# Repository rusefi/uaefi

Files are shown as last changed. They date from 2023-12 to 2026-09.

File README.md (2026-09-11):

# Ultra Affordable EFI

🟢[$275 base model rusEFI store](https://www.shop.rusefi.com/shop/p/uaefi-ultra-affordable-efi)🟢

## Community Support

🔴Community support ONLY 🔴 https://www.facebook.com/groups/rusEfi 🔴 [Discord](https://github.com/rusefi/rusefi/wiki/Discord)🔴 [Commercial Support](https://www.shop.rusefi.com/shop/p/details-about-rusefi-ecu-technical-support) 🔴

## Technical Details

Open Source KiCAD hardware powered by [Hellen-One](https://github.com/andreika-git/hellen-one)

Powered by [rusEFI firmware](https://github.com/rusefi/rusefi)

[User Documentation](https://github.com/rusefi/rusefi/wiki/uaEFI)





## MCU options

1mb of flash is _required_.

One day we shall try https://jlcpcb.com/partdetail/Stmicroelectronics-STM32F427VIT6%2FC57097#EC or https://jlcpcb.com/partdetail/Stmicroelectronics-STM32F437VIT7%2FC1338578#EC

## HOWTO JLCPCB

You would need three files from ``boards/uaefi-a/board`` folder to place your JLCPB Assembly order: gerber.zip BOM-JLC.csv and CPL.csv

### Q: having trouble with opening uaefi board project. library path seems ok, i do not know how to solve missing modules issue

A: missing modules are closed source. they are filled in by github magic
github magic combines gerbers and spits out a complete bom/pcl/new gerbers to upload to jlc/friends. See https://github.com/rusefi/hellen-one/tree/master?tab=readme-ov-file#tldr for more info

### Q: Magic modules? How do I see schematics of those?

A: https://github.com/rusefi/hellen-one has full documentation for each module

### Q: Something wrong with BOM?

A: Nope, that's normal nothing to worry about click 'Continue'.



### Q: how do I get more RAM for Lua?

A: fabricate with STM32F42xVI firmware would defect extra RAM and give you extra Lua. Once your script does not fit into STM32F42xVI it's F7 time or help us leverage F413.

### Q: I've place an order with JLCPCB and I see scary looking wrong orientation?

A: that's expected. See [boards/uaefi-c/board](boards/uaefi-c/board) ``Original*.png`` files and ``Produce*.png`` after JLCPCB manual review process.

## Bluetooth power issue fix

It was found that board with installed BT module may be affected by power issue.

During power on BT module consume too much inrush current on 3.3V line causing 3.3V drop below MCU reset hreshold. This may lead to unstable start or infinity reset loop.

To fix this please install additional capacitors to 5V and 3.3V powerlines.

Polarized electrolytic capacitors with at least 10V rating and extended temperature range are recommended. Tantalum and solid electrolytic capacitors are also suitable.

**Please carefully follow illustrated polarity.**

33..47uF should be added to 5V powerrail. [This](https://www.digikey.com/en/products/detail/w%C3%BCrth-elektronik/860020372004/5727028) or [this](https://www.digikey.com/en/products/detail/w%C3%BCrth-elektronik/860080372001/5727224) or [any of these](https://www.digikey.com/en/products/filter/aluminum-electrolytic-capacitors/58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).



And 220..470uF should be added to 3.3V powerrail. [This](https://www.digikey.com/en/products/detail/w%C3%BCrth-elektronik/860010273011/5726952) or [this](https://www.digikey.com/en/products/detail/w%C3%BCrth-elektronik/860020273011/5727148) or [any of these](https://www.digikey.com/en/products/filter/aluminum-electrolytic-capacitors/58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).



## HOWTO EGT chip

This board has a placeholder for MAX31855 (or MAX6675) termocouple-to-digital chip. **This chip is not populated by default!**

Screenshot from 2025-09-26 11-15-15

D8 is **optional** ESD protection and also is not populated by default. You need to solder U4 only, D8 is optional. All passive components are already populated.

**MAX31855** works without addtional modification.

For **MAX6675** connect EGT- to GNDA either on J2 "C" connector or just short C28 (replace with 0R).

Screenshot from 2025-09-26 11-19-41

## [EXPERIMENTAL] How to make MAX9924 work with low tooth count trigger wheel

In some cases user may need two VR inputs on UAEFI and both trigger wheels are low-tooth count.

In default configuration MAX9924 does not work with low count trigger wheels because of its "adaptive peak threshold" and its watchdog.

Screenshot from 2025-10-12 16-58-30

On UAEFI MAX9924 is configured in **A2 mode**.

Screenshot from 2025-10-12 16-59-49

**B mode** allow use of MAX9924 with low count trigger wheels. But external Bias and Thresholt voltages should be allpied. Both can be sources from UAEFI Discrete VR module.

List of modifications:
1. pin 6: ZERO_EN connect to VCC instead of GND.
2. pin 4: supply 2.5 V instead of GND
3. pin 8: EXT, supply external threshold voltage

Pins 4 and 6 needs to be lifted from PCB to be disconnected from GND. Pin 8 initially is not connected to any circuit.

Use hot air gun to de-solder whole chip. Then twist pins 4 and 6 up so both do not touch PCB. Then solder chip back to PCB

Now use thin wire to connect:
1. pin 6 to pin 10 of the same chip.
2. pin 4 to **Vref** at R769 + C754. See [iBOM](https://github.com/rusefi/uaefi/blob/main/boards/uaefi-d/board/uaefi-d-ibom.html) for its locations
3. pin 8 to **thresh_high** at U756 pin 1. See [iBOM](https://github.com/rusefi/uaefi/blob/main/boards/uaefi-d/board/uaefi-d-ibom.html) for its locations



Now MAX9924 VR input uses same threshold vs RPM settings that is set for Descrete VR input. And it is cabable to work with low tooth count trigger wheels without noise issues.

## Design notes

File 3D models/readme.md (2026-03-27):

Unofficial enclosure By Kim https://www.thingiverse.com/thing:6498664

Unofficial enclosure By Light-r4y https://github.com/Light-r4y/uaEFI_case

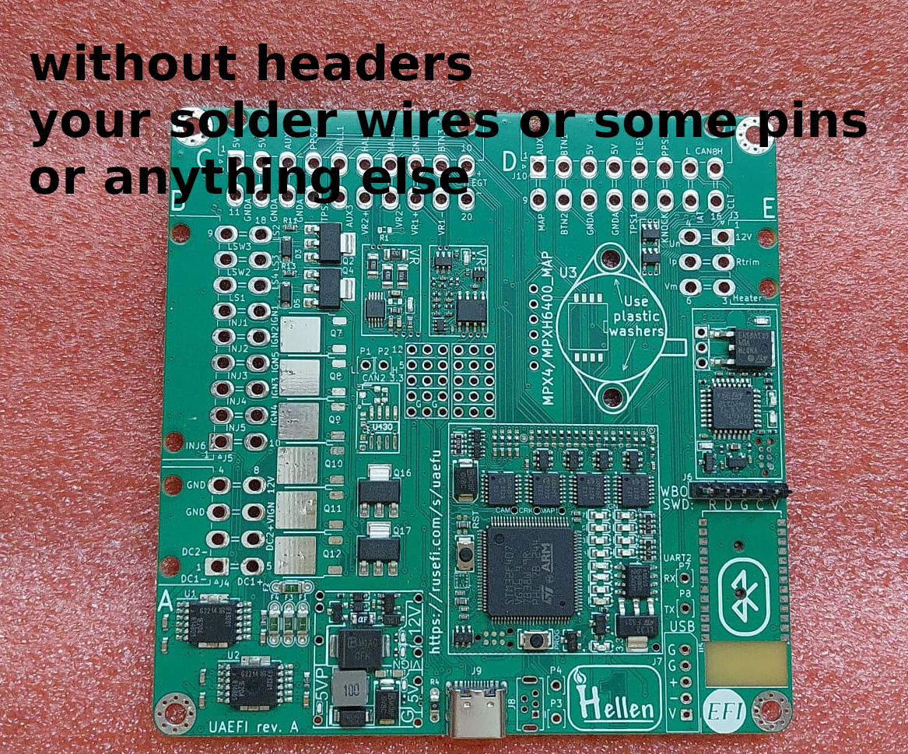
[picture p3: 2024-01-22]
docs/without-headers.png

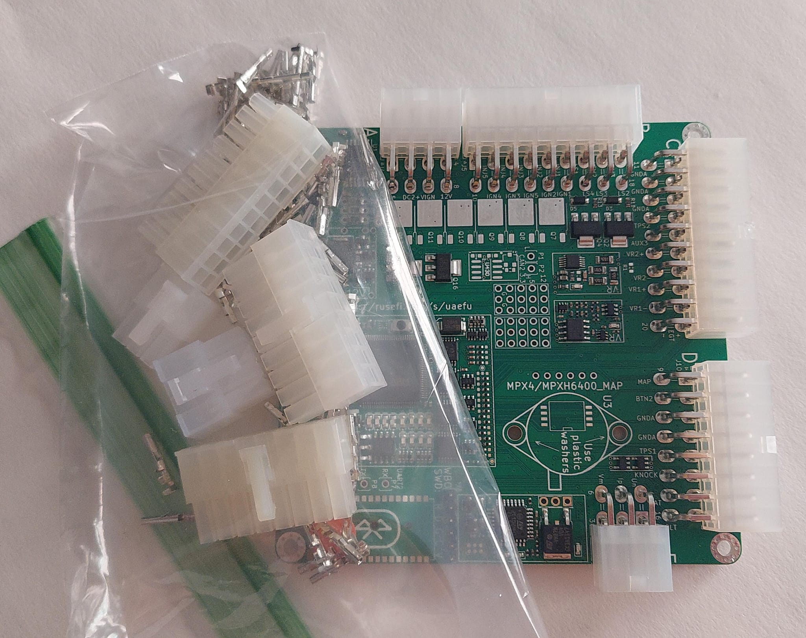
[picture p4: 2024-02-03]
docs/with-crimp-kit.jpg

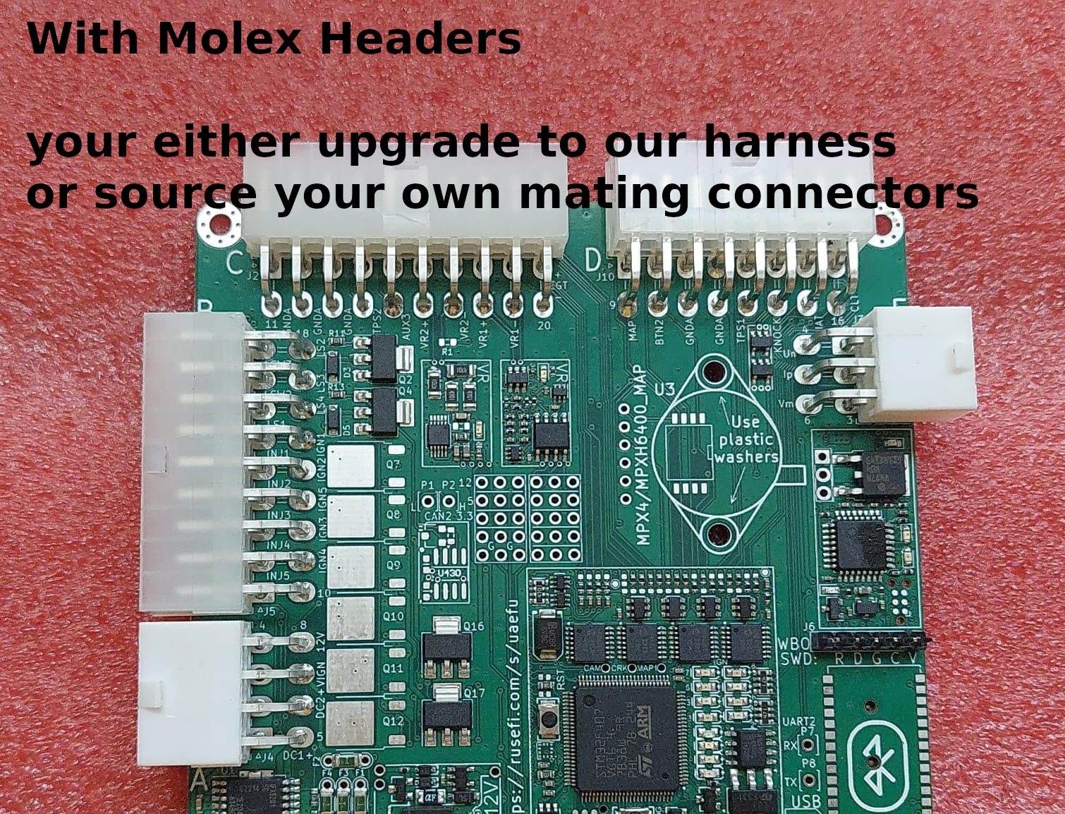
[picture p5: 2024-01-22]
docs/with-headers.png

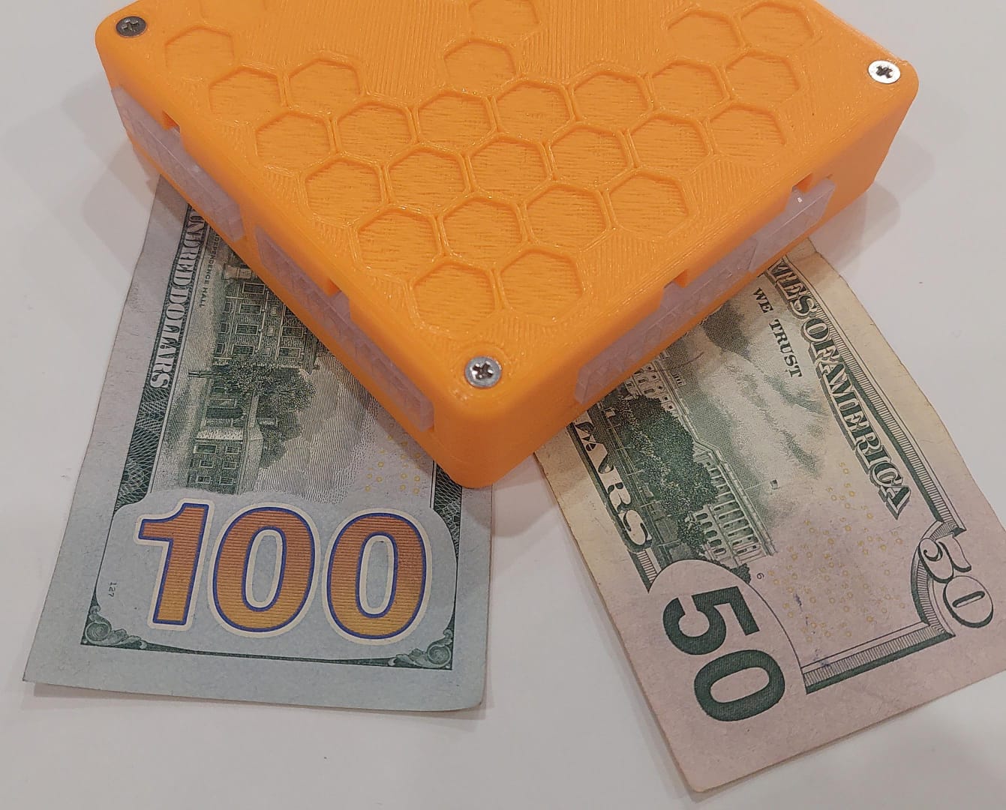
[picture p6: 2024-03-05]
docs/orange-150.jpg

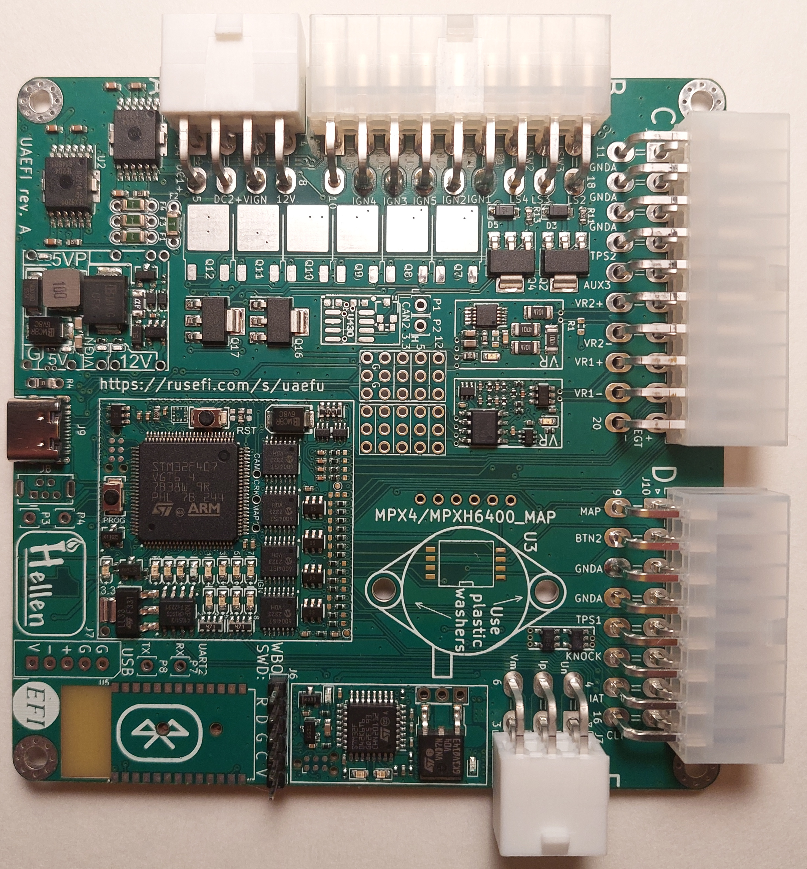
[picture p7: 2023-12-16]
docs/uaefi-a-top-high-res.jpg

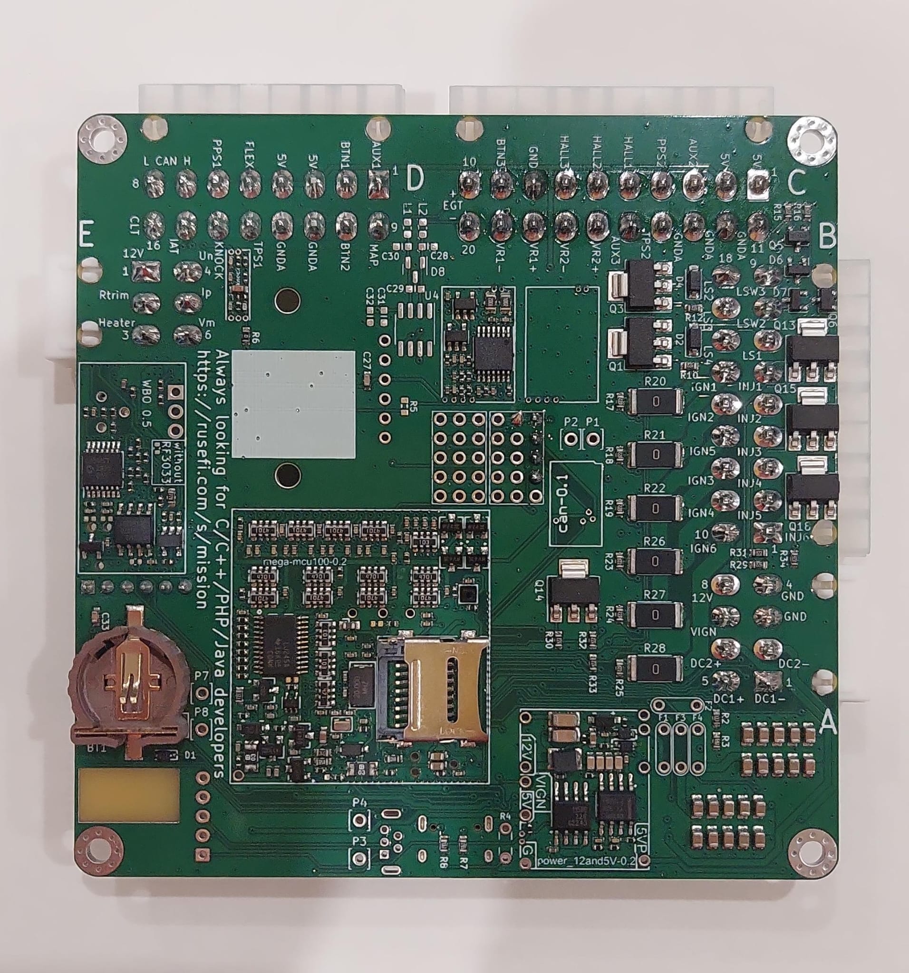
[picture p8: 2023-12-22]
docs/base-bottom.jpg

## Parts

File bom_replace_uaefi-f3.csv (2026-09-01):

#include hellen-one/global-replace.csv
# remove +5V pull-ups from SPI1, because we use it with +3.3v accelerometer
R103,
R105,
# remove jumper resistor connecting BOOT1 with A22 input line, because we use STM32F4
R131,
#CAN wakeup disabled, O2S input enabled
R145,
#PWR_EN not used as GPIO
R142,
# cost reduction
U106,
# DNP BLUETOOTH JDY
U5,
# DNP EGT
D8,
U4,
# STM32F407VGT6 is very cheap
U105,"STM32F407VGT6","LQFP100","C12345"
#without CAN2
"C430,C431,D430,R430,U430",
#VNLD5090
"U6,U7,U8,U9,U10,U11","VNLD5090","SO-8","C222209"
#79 RTC battery drain
D107,
# availability and cost reduction
J2,"5569-20A2","2x10P 2 4.2mm Female pin 4.2mm","C2845795"
J3,"5569-06A2","2x3P 2 4.2mm 4.2mm 3 Brass Push-Pull","C19188572"
J4,"5569-08A2","2x4P 2 Tin 4.2mm Female 4.2mm","C388760"
J5,"5569-18A2","2x9P 2 4.2mm Female 4.2mm 9 Right-Angle","C725776"
J10,"39301160","02x08_4.2mm","C5355564"
# Q1 options
# ZXMS6005SGTA C174042
# ZXMS6005DGTA C174045
# NCV8440ASTT3G C604063
# would VNL5160 work? would VNL5160 be the cheapest option?
# cost
"D411","PSM712-LF","SOT-23","C5180294"
# same board ID as rev A for now!
#include hellen-one/board_id/generated/board_id_uaefi-a.csv
#include bom_pullups_uaefi-f3.csv

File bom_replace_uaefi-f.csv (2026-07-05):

#include hellen-one/global-replace.csv
# remove +5V pull-ups from SPI1, because we use it with +3.3v accelerometer
R103,
R105,
# remove jumper resistor connecting BOOT1 with A22 input line, because we use STM32F4
R131,
#CAN wakeup disabled, O2S input enabled
R145,
#PWR_EN not used as GPIO
R142,
# DC-DC Inductor
L421,"MWSA0503S-100MT","MWSA0503","C408412"
L420,"NLCV32T-2R2M-EF","L1210","C250227"
# fuses
F410,"nSMD050-24V","SMD1206","C70076"
# replacement not needed "F1,F2,F3,F4","5A","F1206","C553924"
# TLS115
U411,"TLS115B0EJXUMA1","PG-DSO-8","C3747428"
#MAX9142
U754,"TLV3202AIDR","SO8","C129325"
# cost reduction
U106,
# DNP BLUETOOTH JDY
U5,
# more proper part and shelf
"U1,U2","TLE9201SG","Infineon_PG-DSO-12-11","C2653438"
# DNP EGT
D8,
U4,
R420,"1","R0402","C2770750"
U107,"LPS22","HLGA-10L","C2827824"
U410,"LP2981-33DBVR","SOT-23-5","C129997"
U602,"STM32F042K6T7","LQFP-32","C1337340"
"C603","33n","C0402","C106862"
#Knock capacitor
"C471","3.3n","C0402","C107028"
# max9924
U771,"MAX9924UAUB+T","MSOP10","C5145181"
# STM32F407VGT6 is very cheap
U105,"STM32F407VGT6","LQFP100","C12345"
#without CAN2
"C430,C431,D430,R430,U430",
#20MHz crystal
# replacement not needed Y102,"TXM20M0002503LFBEO00T","SMD5032-2P","C362485"
#SD Card
J100,"TF-014-H16","SMD","C125814"
#board ID capacitor shortage
"C123,C133","1u","C0603","C14664"
R609,"61.9","R0603","C321964"
#VNLD5090
"U6,U7,U8,U9,U10,U11","VNLD5090","SO-8","C222209"
#mux
"U755,U756","WAS3157B-6","SOT-363","C213161"
#78 IGN buf switch to SN74LXCH8T245PWR
U103,"SN74LXCH8T245PWR","TSSOP-24","C2918963"
#79 RTC battery drain
D107,
# availability and cost reduction
J2,"5569-20A2","2x10P 2 4.2mm Female pin 4.2mm","C2845795"
J3,"5569-06A2","2x3P 2 4.2mm 4.2mm 3 Brass Push-Pull","C19188572"
J4,"5569-08A2","2x4P 2 Tin 4.2mm Female 4.2mm","C388760"
J5,"5569-18A2","2x9P 2 4.2mm Female 4.2mm 9 Right-Angle","C725776"
J10,"39301160","02x08_4.2mm","C5355564"
# Q1 options
# ZXMS6005SGTA C174042
# ZXMS6005DGTA C174045
# NCV8440ASTT3G C604063
# would VNL5160 work? would VNL5160 be the cheapest option?
# cost
"D411","PSM712-LF","SOT-23","C5180294"
#LEDs
"D106","YELLOW_LED","LED0603","C165983"
"D751,D771,D601,D104,D108","GREEN_LED","LED0603","C965804"
"D602,D105,D109,D110,D111,D112,D113,D114,D115,D116","BLUE_LED","LED0603","C497940"
"LED1, LED2, LED3, LED4","BLUE_LED","LED0402","C434447"
# same board ID as rev A for now!
#include hellen-one/board_id/generated/board_id_uaefi-a.csv
#include bom_pullups_uaefi-f.csv

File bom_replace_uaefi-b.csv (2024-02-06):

# remove +5V pull-ups from SPI1, because we use it with +3.3v accelerometer
R103,
R105,
# remove jumper resistor connecting BOOT1 with A22 input line, because we use STM32F4
R131,
#CAN wakeup disabled, O2S input enabled
R145,
#PWR_EN not used as GPIO
R142,
# DC-DC Inductor
L421,"MWSA0503S-100MT","MWSA0503","C408412"
L420,"NLCV32T-2R2M-EF","L1210","C250227"
# fuses
F410,"nSMD050-24V","SMD1206","C70076"
# TLS115
U411,"TLS115B0EJXUMA1","PG-DSO-8","C3743696"
# cost reduction
U106,
# STM32F407VGT6 is very cheap
U105,"STM32F407VGT6","LQFP100","C12345"
#without CAN2
"C430,C431,D430,R430,U430",
#20MHz crystal
Y102,"TXM20M0002503LFBEO00T","SMD5032-2P","C362485"
#SD Card
J100,"TF-014-H16","SMD","C125814"
#board ID capacitor shortage
C133,"1u","C0603","C519559"
#mux
"U755,U756","WAS3157B-6","SOT-363","C213161"
# availability and cost reduction
J2,"5569-20A2","2x10P 2 4.2mm Female pin 4.2mm","C2845795"
J3,"5569-06A2","2x3P 2 4.2mm 4.2mm 3 Brass Push-Pull","C190915"
J4,"5569-08A2","2x4P 2 Tin 4.2mm Female 4.2mm","C388760"
J5,"5569-18A2","2x9P 2 4.2mm Female 4.2mm 9 Right-Angle","C725776"
J10,"39301160","02x08_4.2mm","C5355564"
# Q1 options
# ZXMS6005SGTA C174042
# ZXMS6005DGTA C174045
# NCV8440ASTT3G C604063
# would VNL5160 work? would VNL5160 be the cheapest option?
# cost
"D6, D7, D411","PSM712-LF","SOT-23","C5180294"
#LEDs
"D751,D771,D601,D104,D108","GREEN_LED","LED0603","C965804"
"D602,D105,D109,D110,D111,D112,D113,D114,D115,D116","BLUE_LED","LED0603","C497940"
"LED1, LED2, LED3, LED4","BLUE_LED","LED0402","C2844007"
# same board ID as rev A for now!
#include hellen-one/board_id/generated/board_id_uaefi-a.csv
#include bom_pullups_uaefi-b.csv

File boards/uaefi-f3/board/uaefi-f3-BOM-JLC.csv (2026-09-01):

Comment | Designator | Footprint | LCSC Part #
CR1220 | BT1 | CR1220-2 | C70381
10u | C1, C2, C3, C4, C5, C6, C7, C8, C9, C10, C14, C15, C16, C17, C18, C19, C20, C21, C22, C23 | C0805 | C15850
100n | C11, C24, C27, C29, C31, C33, C772 | C0603 | C14663
10n | C12, C13, C25, C26, C28, C30 | C0603 | C57112
1u | C32 | C0603 | C15849
1N4148WS | D1, D410, D412, D413, D414 | SOD-323 | C2128
B5819W | D2, D3, D4, D5, D416, D417, D101 | SOD-123 | C8598
Fuse | F1, F2, F3, F4 | Fuse_1206_3216Metric_Pad1.42x1.75mm_HandSolder | C182446
50mA | F5, F6, F7, F8, F9, F10 | Fuse_0603_1608Metric | C369141
Conn_01x06 | J6 | PinHeader_1x06_P2.54mm_Vertical | C37208
USB_C | J9 | USB_C | C2927038
470R@100MHz | L1, L2 | L_0603_1608Metric | C97853
33k | R2, R120 | R0603 | C4216
6.8k | R3 | R0603 | C23212
4.7k | R4, R9, R10, R11, R12, R13, R14, R15, R16, R29, R30, R31, R32, R33, R34, R41, R42, R43, R44, R45, R46, R47, R48, R49, R50, R51 | R0603 | C23162
0 | R6 | R0603 | C21189
5.6k | R7, R8 | R0603 | C23189
22 | R17, R18, R19, R23, R24, R25 | R0603 | C23345
0 | R20, R21, R22, R26, R27, R28 | R2512 | C25469
10k | R35, R36, R37, R752, R753 | R0805 | C17414
TLE9201SG | U1, U2 | Infineon_PG-DSO-12-11 | C2653438
47u | C410, C412 | C1206 | C96123
100n | C411, C413, C420, C470, C228 | C0402 | C307331
1u | C414, C415, C755, C758, C761, C762, C763, C765, C766, C767, C600, C607, C609, C610, C611 | C0402 | C52923
10u | C421, C422, C423, C424, C425 | C0603 | C96446
47u | C426 | C0603 | C140782
4.7u | C427, C616 | C0603 | C19666
10n | C428, C756, C757, C760, C764, C768, C769, C203, C202, C201, C200, C214, C215, C225, C226, C227 | C0402 | C15195
220p | C429 | C0402 | C1530
BAS416 | D415 | SOD-323 | C968040
SMCJ30A | D418 | SMC | C310046
SS34 | D420 | SMA | C8678
P6SMB6.8CA | D421, D205 | SMB | C78395
SMD1206P050TF/24 | F410 | SMD1206 | C369160
2.2uH | L420 | L1210 | C250227
MWSA0503-10uH | L421 | MWSA0503 | C325966
MHT136UGCT | LED1, LED2, LED3, LED4 | LED0402 | C434447
6.8k | R410, R413 | R0402 | C93940
33k | R411, R424, R425, R474 | R0402 | C25779
1 | R420 | R0402 | C25147
10k | R421, R426, R427, R757, R762, R763, R767, R768, R604, R605, R613, R614, R618, R619, R625, R102, R107, R108, R109, R121, R127, R128, R141, R219 | R0402 | C60490
68k | R422, R760, R602, R603 | R0402 | C137947
12k | R423, R472, R754 | R0402 | C25752
4.7k | R428, R144, R202, R201, R124, R126, R132 | R0402 | C25900
MIC5205-3.3YM5 | U410 | SOT23-5 | C129997
TLS115 | U411 | PG-DSO-8 EP | C3743696
LMR14020 | U420 | SOP8 | C187824
3.3n | C471 | C0402 | C26404
330p | C472 | C0402 | C13533
47p | C473 | C0402 | C1567
680p | C474 | C0603 | C1630
470k | R470 | R0402 | C137976
100k | R471, R473, R755, R756, R758, R759, R615, R621 | R0402 | C25741
LMV321IDBVR | U470, U471 | SOT23-5 | C7972
1n | C751, C135, C139, C141, C142, C211, C209, C208, C212, C213, C210, C143, C144, C145, C146 | C0402 | C1523
470n | C752 | C0402 | C47339
100n | C753, C754, C759, C601, C602, C605, C608, C612, C613, C614, C615, C617, C618, C100, C101, C105, C108, C111, C112, C113, C119, C120, C122, C124, C126, C127, C130, C134, C147, C180, C185, C190, C195, C220, C221, C222 | C0402 | C1525
LED-GREEN-0603 | D751, D771, D601, D104, D108 | LED-0603 | C965804
2.2k | R751, R122, R123, R146, R147 | R0402 | C25879
10 | R761, R764, R769, R606, R110, R111, R112, R113, R114, R115, R116, R117 | R0402 | C25077
1k | R765, R766, R600, R601, R616, R617, R622, R626, R627, R628 | R0402 | C11702
SRV05-4-P-T7 | U751, D102, D200, D202, D203, D206 | SOT23-6 | C85364
74AHC1G02 | U752, U757 | SOT23-5 | C7463
MCP6004 | U753, U600, U180, U185, U190, U195 | TSSOP14 | C50282
MAX9142 | U754 | SO8 | C129325
NC7SB3157P6X | U755, U756 | SOT-363 | C87403
1n | C771 | C0603 | C1588
22u | C773 | C0603 | C59461
4.7k | R771, R772, R773, R774 | R1206 | C17936
10k | R776, R777, R134 | R0603 | C167144
MAX9924UAUB+ | U771 | MSOP-10_3x3mm_P0.5mm | C143633
33n | C603 | C0402 | C106862
LED-RED-0603 | D600, D603, D103 | LED-0603 | C2286
LED-BLUE-0603 | D602, D105, D109, D110, D111, D112, D113, D114, D115, D116 | LED-0603 | C497940
PESD1CAN | D604, D100 | SOT-23 | C5261084
VNN7NV04PTR-E | Q600 | SOT-223 | C501115
22k | R607 | R0402 | C25768
47 | R608 | R0402 | C25118
61.9 | R609 | R0603 | C227998
20k | R610, R611, R612 | R0402 | C25765
27k | R620, R623 | R0402 | C25771
3.3k | R624 | R0402 | C25890
AD8628 | U601 | TSOT23-5 | C29309
STM32F042K6Tx | U602 | LQFP32 | C1337340
REF3033 | U603, U102 | SOT-23 | C36658
XC6206P332MR | U604 | SOT-23 | C5446
TJA1051T/3/1J | U605, U100 | SO8 | C38695
SN74LVC4245APWR | U103 | TSSOP24 | C2918963
SN74LVC1G06DCKR | U110 | SC-70-5 | C7828
SMD1206B035TF/16 | F100, F101 | R1206 | C269114
Molex MicroSD 47219-2001 | J100 | SDAMB-012 | C164170
LPS22HBTR | U107 | HLGA-10L | C2827824
LED-YELLOW-0603 | D106 | LED-0603 | C2287
LDL1117S33R | U101 | SOT-223 | C15578
BTN | S100, S101 | SMD-2_2.9x3.9x1.7 | C455280
BLM18AG601SN1D | L100 | L0603 | C19330
BAT54S | VD100, VD101, VD102, VD103 | SOT-23 | C47546
AO3401A | Q100, Q102 | SOT-23 | C15127
AO3400A | Q101, Q103 | SOT-23 | C20917
510 | R254, R255, R256, R258 | R0402 | C25123
470 | R101, R118, R119 | R0603-4 | C25510
120 | R100 | R0603 | C22787
100 | R104, R106 | R0603 | C22775
74LVC2G17GW,125 | U108, U109 | SOT-363 | C80500
32.768 kHz | Y101 | SMD2012 | C99009
20 MHz | Y102 | SMD5032 | C112566
18p | C132, C136 | C0402 | C1549
12p | C115, C116 | C0402 | C1547
10k | R129, R130, R140 | R0603-4 | C29718
5.1k | R195 | R0402 | C25905
4.7u | C102, C103, C104, C106, C107, C137, C138, C140 | C0402 | C23733
4.7k | R125, R180, R181, R185, R186, R190, R191, R196, R197, R200, R218, R227, R245 | R0603-4 | C66697
2.2u | C114, C131, C223, C224, C229 | C0402 | C12530
1u | C123, C133 | C0603 | C519560
0 | R143, R148 | R0402 | C17168
STM32F407VGT6 | U105 | LQFP100 | C12345
VNLD5090 | U6, U7, U8, U9, U10, U11 | SO-8 | C222209
5569-20A2 | J2 | 2x10P 2 4.2mm Female pin 4.2mm | C2845795
5569-06A2 | J3 | 2x3P 2 4.2mm 4.2mm 3 Brass Push-Pull | C19188572
5569-08A2 | J4 | 2x4P 2 Tin 4.2mm Female 4.2mm | C388760
5569-18A2 | J5 | 2x9P 2 4.2mm Female 4.2mm 9 Right-Angle | C725776
39301160 | J10 | 02x08_4.2mm | C5355564
PSM712-LF | D411 | SOT-23 | C5180294
750 | R133 | R0603 | C23241
680k | R222, R220, R208, R207, R234, R235, R232, R233, R250, R251, R252, R225, R135 | R0402 | C4131

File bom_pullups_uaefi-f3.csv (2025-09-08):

#CRANK BUTTON1: UP 680k 1n
R222 | 680k | R0402 | C4131
R226
C211 | 1n | C0402 | C1523
#CAM BUTTON2: UP 680k 1n
R220 | 680k | R0402 | C4131
R224
C209 | 1n | C0402 | C1523
#VSS FLEX: UP 10k 1n
R219 | 10k | R0402 | C25744
R223
C208 | 1n | C0402 | C1523
#TPS TPS1: DOWN 680k 10n
R204
R208 | 680k | R0402 | C4131
C203 | 10n | C0402 | C15195
#PPS PPS1: DOWN 680k 10n
R203
R207 | 680k | R0402 | C4131
C202 | 10n | C0402 | C15195
#IAT IAT: UP 4.7k 10n
R202 | 4.7k | R0402 | C25900
R206
C201 | 10n | C0402 | C15195
#CLT CLT: UP 4.7k 10n
R201 | 4.7k | R0402 | C25900
R205
C200 | 10n | C0402 | C15195
#O2S AUX1: DOWN 680k 10n
R230
R234 | 680k | R0402 | C4131
C214 | 10n | C0402 | C15195
#O2S2 AUX2: DOWN 680k 10n
R231
R235 | 680k | R0402 | C4131
C215 | 10n | C0402 | C15195
#MAP1 MAP: DOWN 680k 1n
R228
R232 | 680k | R0402 | C4131
C212 | 1n | C0402 | C1523
#MAP2 INTERNAL_MAP: DOWN 680k 1n
R229
R233 | 680k | R0402 | C4131
C213 | 1n | C0402 | C1523
#AUX1 TPS2: DOWN 680k 10n
R246
R250 | 680k | R0402 | C4131
C225 | 10n | C0402 | C15195
#AUX2 PPS2: DOWN 680k 10n
R247
R251 | 680k | R0402 | C4131
C226 | 10n | C0402 | C15195
#AUX3 AUX3: DOWN 680k 10n
R248
R252 | 680k | R0402 | C4131
C227 | 10n | C0402 | C15195
#AUX4 VMAIN: DOWN DNP 100n
R249
R253
C228 | 100n | C0402 | C307331
#KNOCK KNOCK: DOWN 680k 1n
R221
R225 | 680k | R0402 | C4131
C210 | 1n | C0402 | C1523
#D1 HALL1: UP 4.7k 1n
R124 | 4.7k | R0402 | C25900
R136
C143 | 1n | C0402 | C1523
#D2 HALL2: UP 4.7k 1n
R126 | 4.7k | R0402 | C25900
R137
C144 | 1n | C0402 | C1523
#D3 HALL3: UP 4.7k 1n
R132 | 4.7k | R0402 | C25900
R138
C145 | 1n | C0402 | C1523
#D4 BUTTON3: UP 680k 1n
R135 | 680k | R0402 | C4131
R139
C146 | 1n | C0402 | C1523

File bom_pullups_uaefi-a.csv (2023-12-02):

#CRANK BUTTON1: UP 10k 100n
R222 | 10k | R0402 | C25744
R226
C211 | 100n | C0402 | C307331
#CAM BUTTON2: UP 10k 100n
R220 | 10k | R0402 | C25744
R224
C209 | 100n | C0402 | C307331
#VSS FLEX: UP 10k 1n
R219 | 10k | R0402 | C25744
R223
C208 | 1n | C0402 | C1523
#TPS TPS1: DOWN 680k 10n
R204
R208 | 680k | R0402 | C163456
C203 | 10n | C0402 | C15195
#PPS PPS1: DOWN 680k 10n
R203
R207 | 680k | R0402 | C163456
C202 | 10n | C0402 | C15195
#IAT IAT: UP 4.7k 10n
R202 | 4.7k | R0402 | C25900
R206
C201 | 10n | C0402 | C15195
#CLT CLT: UP 4.7k 10n
R201 | 4.7k | R0402 | C25900
R205
C200 | 10n | C0402 | C15195
#O2S AUX1: DOWN 680k 10n
R230
R234 | 680k | R0402 | C163456
C214 | 10n | C0402 | C15195
#O2S2 AUX2: DOWN 680k 10n
R231
R235 | 680k | R0402 | C163456
C215 | 10n | C0402 | C15195
#MAP1 MAP: DOWN 680k 1n
R228
R232 | 680k | R0402 | C163456
C212 | 1n | C0402 | C1523
#MAP2 INTERNAL_MAP: DOWN 680k 1n
R229
R233 | 680k | R0402 | C163456
C213 | 1n | C0402 | C1523
#AUX1 TPS2: DOWN 680k 10n
R246
R250 | 680k | R0402 | C163456
C225 | 10n | C0402 | C15195
#AUX2 PPS2: DOWN 680k 10n
R247
R251 | 680k | R0402 | C163456
C226 | 10n | C0402 | C15195
#AUX3 AUX3: DOWN 680k 10n
R248
R252 | 680k | R0402 | C163456
C227 | 10n | C0402 | C15195
#AUX4 VMAIN: DOWN DNP 100n
R249
R253
C228 | 100n | C0402 | C307331
#KNOCK KNOCK: DOWN 680k 1n
R221
R225 | 680k | R0402 | C163456
C210 | 1n | C0402 | C1523
#D1 HALL1: UP 4.7k 1n
R124 | 4.7k | R0402 | C25900
R136
C143 | 1n | C0402 | C1523
#D2 HALL2: UP 4.7k 1n
R126 | 4.7k | R0402 | C25900
R137
C144 | 1n | C0402 | C1523
#D3 HALL3: UP 4.7k 1n
R132 | 4.7k | R0402 | C25900
R138
C145 | 1n | C0402 | C1523
#D4 BUTTON3: UP 10k 100n
R135 | 10k | R0402 | C25744
R139
C146 | 100n | C0402 | C307331

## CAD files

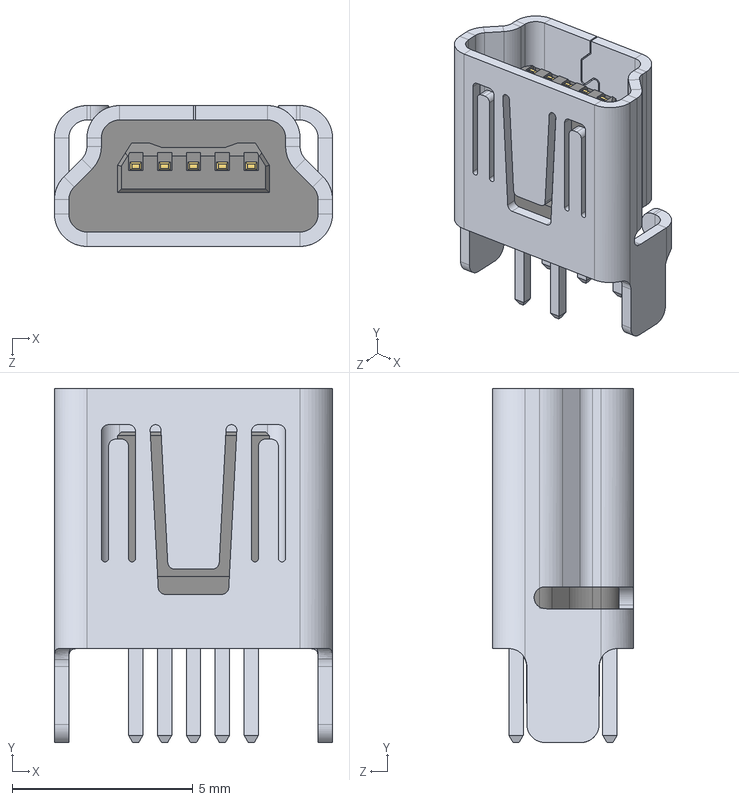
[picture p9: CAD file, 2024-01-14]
3D models/User Library-UE25BE5510H.STEP
7.70 x 9.80 x 3.90 mm

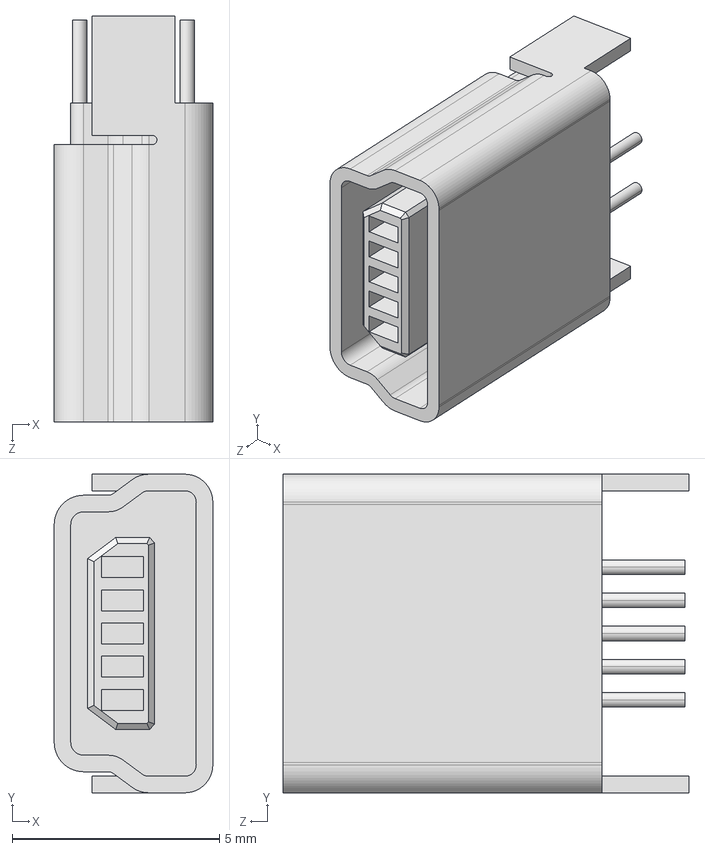
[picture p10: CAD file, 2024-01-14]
3D models/User Library-USB-B-Vert-MINI.STEP
3.83 x 7.69 x 9.80 mm

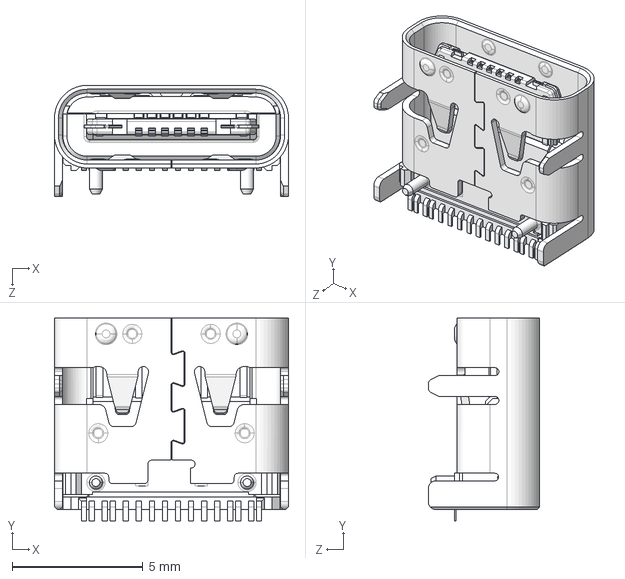
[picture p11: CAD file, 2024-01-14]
3D models/User Library-USB - C.STEP
8.95 x 7.75 x 4.26 mm

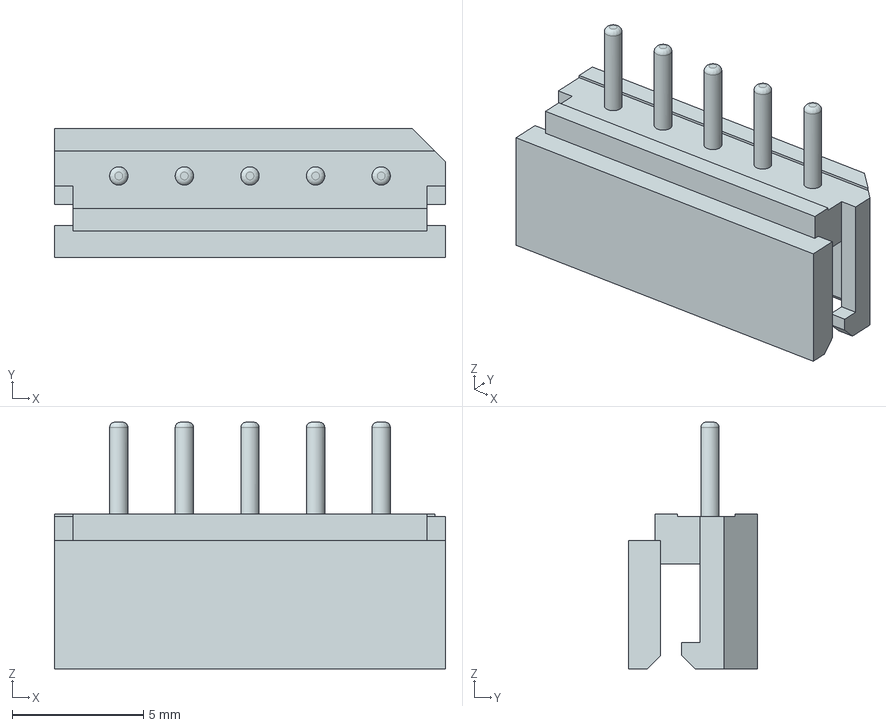
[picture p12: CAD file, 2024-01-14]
3D models/022035055.stp
14.9 x 4.90 x 9.40 mm

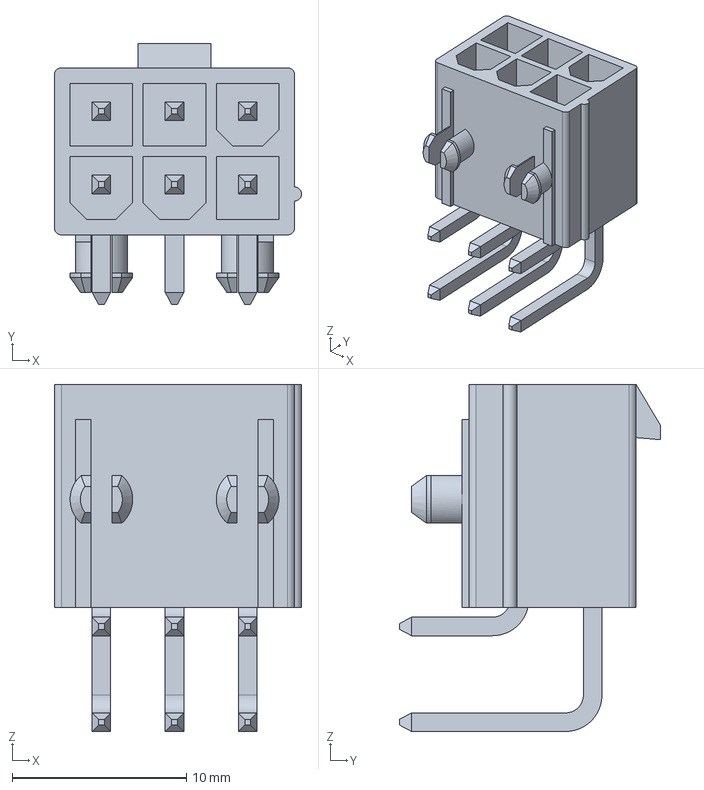
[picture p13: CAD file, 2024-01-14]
3D models/039301060.stp
14.2 x 15.0 x 19.9 mm

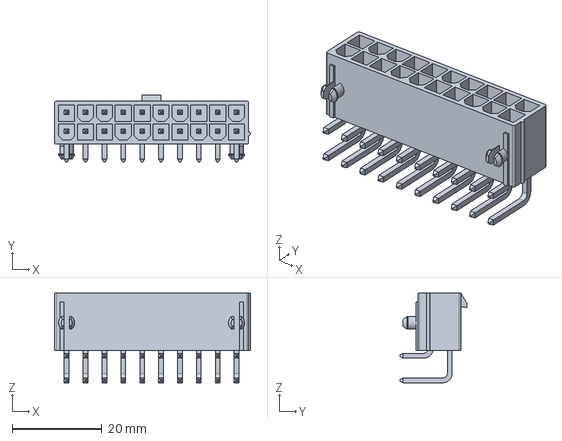
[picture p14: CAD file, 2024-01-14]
3D models/039301200.stp
43.6 x 15.0 x 19.9 mm

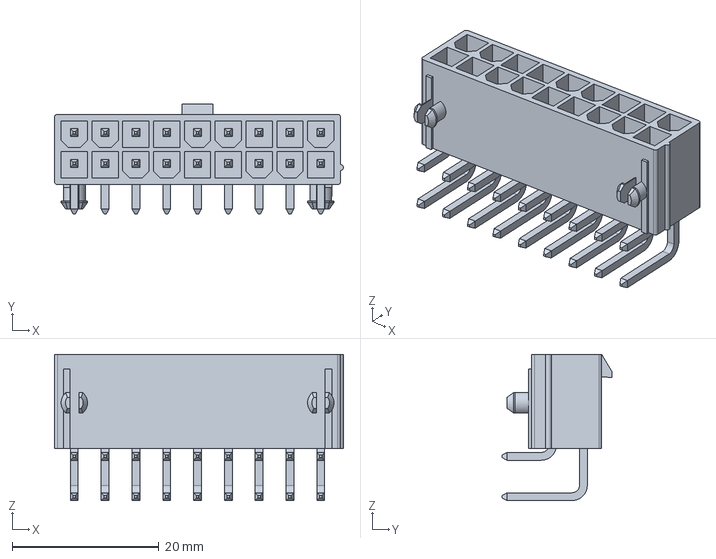
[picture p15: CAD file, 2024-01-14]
3D models/039301180.stp
39.4 x 15.0 x 19.9 mm

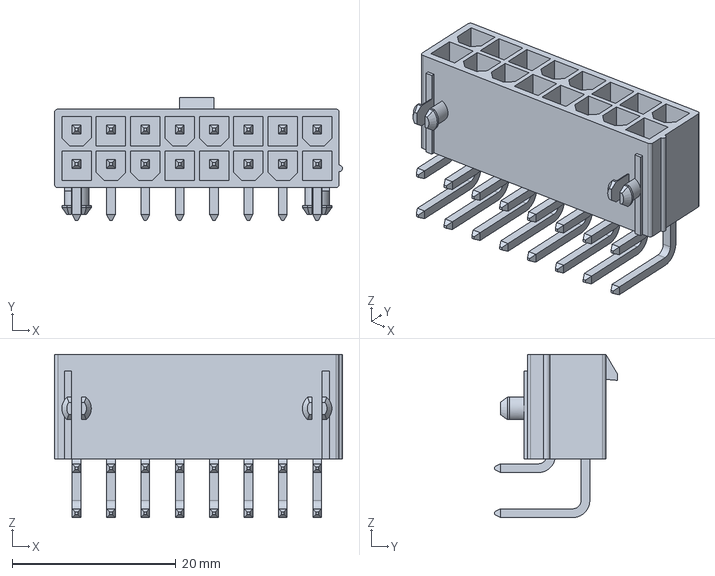
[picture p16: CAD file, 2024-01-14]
3D models/039301160.stp
35.2 x 15.0 x 19.9 mm

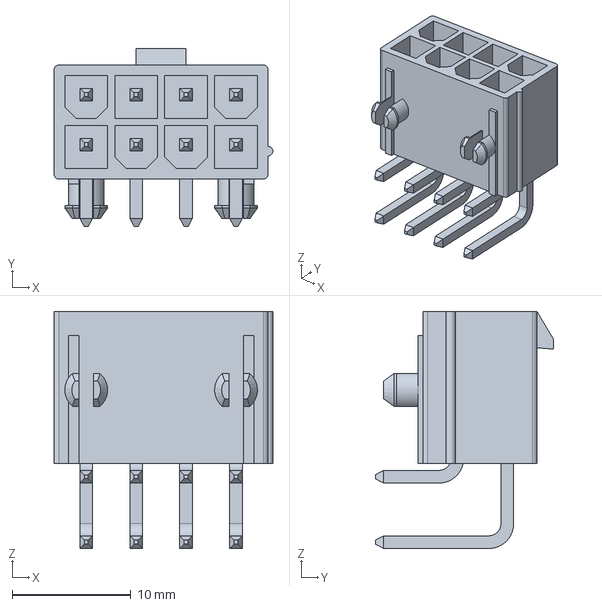
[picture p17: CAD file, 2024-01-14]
3D models/039301080.stp
18.4 x 15.0 x 19.9 mm

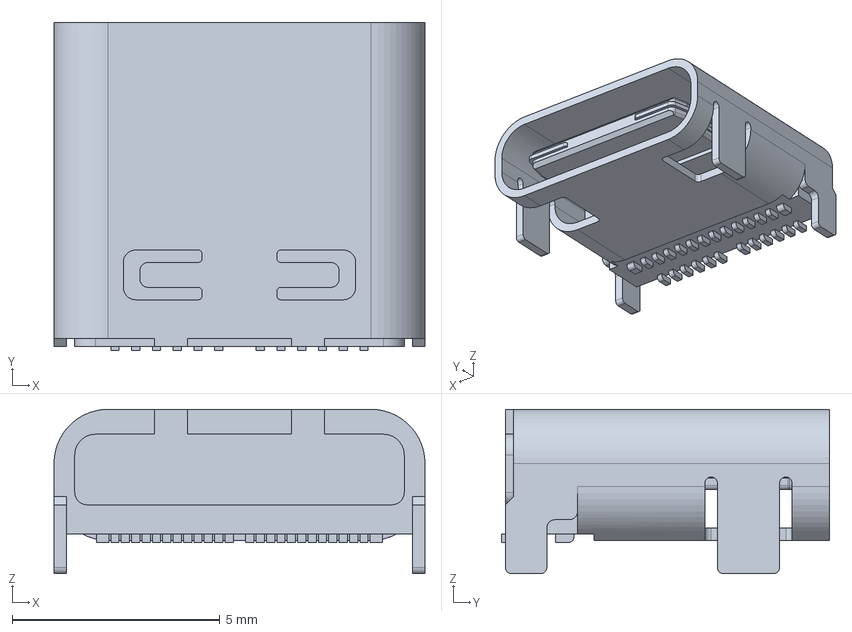
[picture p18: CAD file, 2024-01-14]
3D models/1054500101.stp
8.94 x 7.90 x 3.96 mm

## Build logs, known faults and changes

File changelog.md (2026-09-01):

# rev F3

Sept 2026

better clearance for metal enclosure

# rev F2

July 2026

* resistor moved https://github.com/rusefi/uaefi/issues/110
* QR code added https://github.com/rusefi/uaefi/issues/118

# rev F

July 2026

* series resistor for low side drivers to protect the mcu https://github.com/rusefi/uaefi/issues/114

# rev E-2

April 2026

* upgrade to improved WBO module https://github.com/rusefi/uaefi/issues/107
* some unneeded vias around fuses were removed https://github.com/rusefi/uaefi/issues/106

# rev E

* stronger smart coil buffer https://github.com/rusefi/uaefi/issues/78
* power supply fix for RTC
* https://github.com/rusefi/uaefi/labels/rev-E

# rev D

August 2024

* logic analyzer hookup points for both VRs #66
* minor silkscreen improvements https://github.com/rusefi/uaefi/issues?q=label%3Arev-D+is%3Aclosed

# rev C

Apr 2024

* pad for resistor between VR lines
* a few silkscreen corrections
* full list https://github.com/rusefi/uaefi/issues?q=label%3Arev-C+is%3Aclosed

# rev B

Feb 2024

* [over-current protection on all low side outputs](https://github.com/rusefi/uaefi/issues/44)
* [over-current protection on ignition outputs](https://github.com/rusefi/uaefi/issues/42)
* 0805 button input pull-up/pull-downs added
* button inputs changed from 10K PU to 680K PD https://github.com/rusefi/uaefi/issues/36
* minor cosmetic https://github.com/rusefi/uaefi/labels/rev-B

# rev A

Dec 2023

It works it's great!

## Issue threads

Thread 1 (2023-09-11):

big picture

rusefillc, 2023-09-11:
* mm100
* one max9924 VR with solder-blob jumper to modify into hall input
* one vr-discrete with solder-blob jumper to modify into hall input
* one WBO module
* one knock? two knocks?
* smaller battery holder
* both on-board MAP sensor footprints
* tripled option USB: 1x5 header, vertical mini and flat USB-C

rusefillc, 2023-11-30:
Moved to https://github.com/rusefi/rusefi/wiki/uaEFI#features

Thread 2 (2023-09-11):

fun ticket: STM32F407VGT6 price and availability

rusefillc, 2023-09-11:
https://jlcpcb.com/partdetail/Stmicroelectronics-STM32F407VGT6/C12345

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

rusefillc, 2023-09-11:
See also https://github.com/andreika-git/hellen-one/issues/19

rusefillc, 2023-09-16:
What's going on? stm32 cheaper than Geehy?!

https://jlcpcb.com/partdetail/Geehy-APM32F407VGT6/C2990873

well yes stock goes down let me go grab some more :)

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

ElDominio, 2023-09-16:
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

After 30pc it IS cheaper

Worth it is a different story

rusefillc, 2023-09-21:
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

rusefillc, 2023-09-23:
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

rusefillc, 2023-10-07:
they got more!

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

rusefillc, 2023-11-29:
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

rusefillc, 2023-11-30:
Looks like $4 is the official reality these days

rusefillc, 2024-04-11:
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

Closed 2023-11-30.

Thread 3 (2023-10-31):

ключ

rusefillc, 2023-10-31:
какой же корпус ключа выбрать?

https://jlcpcb.com/partdetail/DiodesIncorporated-ZXMS6005SGTA/C174042

https://jlcpcb.com/partdetail/Stmicroelectronics-VND7NV04TRE/C155605
https://jlcpcb.com/partdetail/Stmicroelectronics-VND10N06TRE/C2149912

https://github.com/andreika-git/hellen-one/issues/256

rusefillc, 2023-10-31:
https://jlcpcb.com/partdetail/DiodesIncorporated-ZXMS6005SGTA/C174042 победил
* sot223 меньше TO-252
* дешевле
* управление от 3в

Closed 2023-11-14.

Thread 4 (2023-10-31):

analog

rusefillc, 2023-10-31:
* TPS/TPS2/PPS/PPS2
* CLT/IAT
* Ignition Switch / Battery Voltage Analog Input
* main relay Voltage Analog Input https://github.com/rusefi/alphax-4chan/issues/166
* external MAP
* x3 aux

rusefillc, 2023-10-31:
Just for fun https://github.com/rusefi/alphax-8chan/issues/16

Closed 2023-11-29.

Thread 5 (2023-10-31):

real life flex input test

rusefillc, 2023-10-31:
Need to confirm 10k pull-up with a real life test ASAP

rusefillc, 2023-11-01:
https://github.com/rusefi/small-can-board/issues/16

rusefillc, 2023-11-01:
10k pull-up confirmed for Flex

Closed 2023-11-29.

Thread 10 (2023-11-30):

Default BOM

rusefillc, 2023-11-30:
Default BOM should be
* [x] one cheaper USB connector
* [x] dnp igbt with 0R jumpers set for smart coils
* [x] dnp EGT
* [x] DNP can2 M7 https://github.com/rusefi/uaefi/issues/6

Closed 2023-12-03.

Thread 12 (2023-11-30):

ABCD all unique part numbers

rusefillc, 2023-11-30:
Same connectors means confused humans, let's have unique ABCD connectors please

rusefillc, 2023-11-30:
@Qwerty-OFF а ещё мне бы номера ответных разъёмов на провода, я их готов заказывать

Qwerty-OFF, 2023-12-02:
39012060
39012080
39012160
39012180
39012200
Вместо последнего "0" можно "5"
39000038 на провод 18-24 AWG

Closed 2023-12-02.

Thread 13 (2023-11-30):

silkscreen

rusefillc, 2023-11-30:
* [x] https://rusefi.com/s/uaefu
* [x] rev A
* [x] "always looking for C/C++..."
* [x] spell out "WBO SWD"
* [x] spell out "USB" next to 5 pin USB

Qwerty-OFF, 2023-12-02:
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

rusefillc, 2023-12-02:
давай или добавим слово "wbo" рядом с swd или заменим?

Qwerty-OFF, 2023-12-02:
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
Нужен QR?

rusefillc, 2023-12-02:
> Нужен QR?

Да нет наверное

Closed 2023-12-02.

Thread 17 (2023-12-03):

дефект рендера или?

rusefillc, 2023-12-03:
отверстия на рендере некоторые не на месте, всё ли хорошо в герберах?

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

rusefillc, 2023-12-03:
герберы живы

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

andreika-git, 2023-12-03:
Нужно проверить, не связано ли это с недавним фиксом rotated+flipped  https://github.com/andreika-git/hellen-one/commit/e4f551ef0aae8d66b00f81f540c980132bd295cf

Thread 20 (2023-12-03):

диагностика КЗ 5в

rusefillc, 2023-12-03:
этот пин про диагностику? у нас есть место добавить для него трассу в один из свободных пинов?

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

Qwerty-OFF, 2023-12-03:
Про диагностику. Свободный пин перестанет быть via. Через джампер?

rusefillc, 2023-12-03:
> Про диагностику. Свободный пин перестанет быть via. Через джампер?

Да

Closed 2023-12-03.

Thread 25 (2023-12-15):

rev A testing

rusefillc, 2023-12-15:
* [x] DFU takes firmware via USB-C
* [x] blue LED blinking with https://github.com/andreika-git/hellen-one/issues/353 workaround
* [x] USB communication
* [x] SD card
* [x] power from external +12v
* [x] CAN bus
* [x] WBO responds to gas
* [x] analog inputs
* [x] low side outpurs
* [x] ign control
* [x] two DC motors
* [x] board id detected correctly: BoardId = 215 BOARD_ID_UAEFI_A
* [ ] on-board baro

rusefillc, 2023-12-15:
red blinks, blue and green are constant ON, no USB connectivity once I've uploaded firmware

@Qwerty-OFF we had it on some board where firmware was constantly rebooting, do not remember what board it was. Solution was maybe to remove a component or something? was it small-can-board?

rusefillc, 2023-12-22:
```
                      ADC says LOW 18@1 0.002v
               sending line=18 value=1
               sending line=18 value=0
17/28 B15 Coil 1 GOOD channel 18
18/28      Toggling port 0
19/28      Toggling port 7
20/28      Toggling port 8
21/28      Toggling port 9
22/28      Toggling port 10
23/28      Toggling port 11
24/28      Toggling port 12
25/28      Toggling port 13
* HAPPY Primary event counter!
* HAPPY VVT1 event counter!
* HAPPY VVT2 event counter!
* HAPPY VSS event counter!
sending DC 0
               Setting ADDR 7
               sending line=40 value=1
                      ADC says LOW 40@0 0.003v
               sending line=40 value=0
                      ADC says HIGH 40@1 3.071v
               sending line=40 value=1
               sending line=40 value=0
               Setting ADDR 7
               sending line=40 value=1
                      ADC says HIGH 40@0 3.069v
               sending line=40 value=0
                      ADC says LOW 40@1 0.003v
               sending line=40 value=1
               sending line=40 value=0
               Setting ADDR 6
               sending line=39 value=1
                      ADC says HIGH 39@0 3.070v
               sending line=39 value=0
                      ADC says LOW 39@1 0.002v
               sending line=39 value=1
               sending line=39 value=0
               Setting ADDR 6
               sending line=39 value=1
                      ADC says LOW 39@0 0.002v
               sending line=39 value=0
                      ADC says HIGH 39@1 3.070v
               sending line=39 value=1
               sending line=39 value=0
GOOD DC=0
         sending DC 1
               Setting ADDR 5
               sending line=38 value=1
                      ADC says LOW 38@0 0.003v
               sending line=38 value=0
                      ADC says HIGH 38@1 3.070v
               sending line=38 value=1
               sending line=38 value=0
               Setting ADDR 5
               sending line=38 value=1
                      ADC says HIGH 38@0 3.068v
               sending line=38 value=0
                      ADC says LOW 38@1 0.002v
               sending line=38 value=1
               sending line=38 value=0
               Setting ADDR 4
               sending line=37 value=1
                      ADC says HIGH 37@0 3.071v
               sending line=37 value=0
                      ADC says LOW 37@1 0.003v
               sending line=37 value=1
               sending line=37 value=0
               Setting ADDR 4
               sending line=37 value=1
                      ADC says LOW 37@0 0.002v
               sending line=37 value=0
                      ADC says HIGH 37@1 3.069v
               sending line=37 value=1
               sending line=37 value=0
GOOD DC=1
          *********************************************** count=1
 ************* ALL GOOD ************************ uptime=412
 ***********************************************
 * Board detected: uaefi rev index 0
 ************* TPS1_1 analog 0 0 voltage=0.529411808 witin range 0.509172384/0.570577344
 ************* TPS1_2 analog 0 1 voltage=0.803921600 witin range 0.767938368/0.860549952
 ************* PPS1 analog 0 2 voltage=0.862745088 witin range 0.821830144/0.920940928
 ************* PPS2 analog 0 3 voltage=0.980392192 witin range 0.960000000/1.399999968
 ************* MAP analog 0 4 voltage=0.627451008 witin range 0.597992960/0.670109504
 ************* CLT analog 0 5 voltage=1.568627456 witin range 1.380596992/1.604477632
 ************* IAT analog 0 6 voltage=0.843137280 witin range 0.811403520/0.942982464
 ************* BATT analog 0 7 voltage=12.814118400 witin range 9.000000000/15.000000000
                      numOutputs 18
               Setting ADDR 0
               sending line=1 value=1
                      ADC says HIGH 1@0 3.094v
               sending line=1 value=0
                      ADC says LOW 1@1 0.002v
               sending line=1 value=1
               sending line=1 value=0
0/28 B1 injector output 6 GOOD channel 1
               Setting ADDR 1
               sending line=2 value=1
                      ADC says HIGH 2@0 3.093v
               sending line=2 value=0
                      ADC says LOW 2@1 0.002v
               sending line=2 value=1
               sending line=2 value=0
1/28 B2 injector output 5 GOOD channel 2
               Setting ADDR 2
               sending line=3 value=1
                      ADC says HIGH 3@0 3.093v
               sending line=3 value=0
                      ADC says LOW 3@1 0.001v
               sending line=3 value=1
               sending line=3 value=0
2/28 B3 injector output 4 GOOD channel 3
               Setting ADDR 3
               sending line=4 value=1
                      ADC says HIGH 4@0 3.092v
               sending line=4 value=0
                      ADC says LOW 4@1 0.001v
               sending line=4 value=1
               sending line=4 value=0
3/28 B4 injector output 3 GOOD channel 4
               Setting ADDR 4
               sending line=5 value=1
                      ADC says HIGH 5@0 3.115v
               sending line=5 value=0
                      ADC says LOW 5@1 0.029v
               sending line=5 value=1
               sending line=5 value=0
4/28 B5 injector output 2 GOOD channel 5
               Setting ADDR 5
               sending line=6 value=1
                      ADC says HIGH 6@0 3.095v
               sending line=6 value=0
                      ADC says LOW 6@1 0.001v
               sending line=6 value=1
               sending line=6 value=0
5/28 B6 injector output 1 GOOD channel 6
               Setting ADDR 6
               sending line=7 value=1
                      ADC says HIGH 7@0 3.115v
               sending line=7 value=0
                      ADC says LOW 7@1 0.028v
               sending line=7 value=1
               sending line=7 value=0
6/28 B7 Low Side output 1 GOOD channel 7
               Setting ADDR 7
               sending line=8 value=1
                      ADC says HIGH 8@0 3.095v
               sending line=8 value=0
                      ADC says LOW 8@1 0.001v
               sending line=8 value=1
               sending line=8 value=0
7/28 B8 Weak Low Side output 2 GOOD channel 8
               Setting ADDR 8
               sending line=9 value=1
                      ADC says HIGH 9@0 3.094v
               sending line=9 value=0
                      ADC says LOW 9@1 0.001v
               sending line=9 value=1
               sending line=9 value=0
8/28 B9 Weak Low Side output 1 GOOD channel 9
               Setting ADDR 9
               sending line=10 value=1
                      ADC says HIGH 10@0 3.088v
               sending line=10 value=0
                      ADC says LOW 10@1 0.002v
               sending line=10 value=1
               sending line=10 value=0
9/28 B16 Low Side output 4 GOOD channel 10
               Setting ADDR 10
               sending line=11 value=1
                      ADC says HIGH 11@0 3.094v
               sending line=11 value=0
                      ADC says LOW 11@1 0.002v
               sending line=11 value=1
               sending line=11 value=0
10/28 B17 Low Side output 3 GOOD channel 11
               Setting ADDR 11
               sending line=12 value=1
                      ADC says HIGH 12@0 3.093v
               sending line=12 value=0
                      ADC says LOW 12@1 0.001v
               sending line=12 value=1
               sending line=12 value=0
11/28 B18 Low Side output 2 GOOD channel 12
               Setting ADDR 12
               sending line=13 value=1
                      ADC says HIGH 13@0 1.152v
               sending line=13 value=0
                      ADC says LOW 13@1 0.001v
               sending line=13 value=1
               sending line=13 value=0
12/28 B10 Coil 6 GOOD channel 13
               Setting ADDR 13
               sending line=14 value=1
                      ADC says HIGH 14@0 1.150v
               sending line=14 value=0
                      ADC says LOW 14@1 0.001v
               sending line=14 value=1
               sending line=14 value=0
13/28 B11 Coil 4 GOOD channel 14
               Setting ADDR 14
               sending line=15 value=1
                      ADC says HIGH 15@0 1.150v
               sending line=15 value=0
                      ADC says LOW 15@1 0.000v
               sending line=15 value=1
               sending line=15 value=0
14/28 B12 Coil 3 GOOD channel 15
               Setting ADDR 15
               sending line=16 value=1
                      ADC says HIGH 16@0 1.151v
               sending line=16 value=0
                      ADC says LOW 16@1 0.001v
               sending line=16 value=1
               sending line=16 value=0
15/28 B13 Coil 5 GOOD channel 16
               Setting ADDR 0
               sending line=17 value=1
                      ADC says HIGH 17@0 1.143v
               sending line=17 value=0
                      ADC says LOW 17@1 0.003v
               sending line=17 value=1
               sending line=17 value=0
16/28 B14 Coil 2 GOOD channel 17
               Setting ADDR 1
               sending line=18 value=1
                      ADC says HIGH 18@0 1.141v
               sending line=18 value=0
                      ADC says LOW 18@1 0.002v
               sending line=18 value=1
               sending line=18 value=0
17/28 B15 Coil 1 GOOD channel 18
18/28      Toggling port 0
19/28      Toggling port 7
20/28      Toggling port 8
21/28      Toggling port 9
22/28      Toggling port 10
23/28      Toggling port 11
24/28      Toggling port 12
25/28      Toggling port 13
* HAPPY Primary event counter!
* HAPPY VVT1 event counter!
* HAPPY VVT2 event counter!
* HAPPY VSS event counter!
sending DC 0
               Setting ADDR 7
               sending line=40 value=1
                      ADC says LOW 40@0 0.003v
               sending line=40 value=0
                      ADC says HIGH 40@1 3.067v
               sending line=40 value=1
               sending line=40 value=0
               Setting ADDR 7
               sending line=40 value=1
                      ADC says HIGH 40@0 3.068v
               sending line=40 value=0
                      ADC says LOW 40@1 0.002v
               sending line=40 value=1
               sending line=40 value=0
               Setting ADDR 6
               sending line=39 value=1
                      ADC says HIGH 39@0 3.068v
               sending line=39 value=0
                      ADC says LOW 39@1 0.003v
               sending line=39 value=1
               sending line=39 value=0
               Setting ADDR 6
               sending line=39 value=1
                      ADC says LOW 39@0 0.002v
               sending line=39 value=0
                      ADC says HIGH 39@1 3.068v
               sending line=39 value=1
               sending line=39 value=0
GOOD DC=0
         sending DC 1
               Setting ADDR 5
               sending line=38 value=1
                      ADC says LOW 38@0 0.002v
               sending line=38 value=0
                      ADC says HIGH 38@1 3.069v
               sending line=38 value=1
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

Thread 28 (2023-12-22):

with wideband warming up sensor batter V reports +5v

rusefillc, 2023-12-22:
* wideband module with sensor hooked up makes a pitched noise, never happened before
* after some warmup time eventually primary ECU battery voltage gauge drops from expected +12v to unexpected +5v

rusefillc, 2023-12-22:
false alarm current was limited on DC supply

Closed 2023-12-22.

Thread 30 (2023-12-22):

ISL9V3040 status

rusefillc, 2023-12-22:
```
The IGBT called out in the Gerber, ISL9V3040D3S, is absolute and no longer sold/manufactured. I would assume finding one with the same properties and package size would make for a good replacement? Or is there another PN recommendation?
```

ISL9V3040S3ST seems active is that the replacement? either way let's have a not dead part on the schematics (not just BOM)

Qwerty-OFF, 2024-01-26:
ISL9V3040**S**3ST это большой корпус
ISL9V3040**D**3ST нам подходит, напишу его на схеме
ISL9V3040D3ST-F085C если что тоже

Closed 2024-01-26.

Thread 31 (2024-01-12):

how about VNL5160 for Qx

rusefillc, 2024-01-12:
VNL5160 (single not VNLD) be an option for Qx?

https://jlcpcb.com/partdetail/Stmicroelectronics-VNL5160N3TRE/C262999

rusefillc, 2024-01-12:
might end up being cheapest option?

Qwerty-OFF, 2024-01-26:
VNL5160 may not be opened by STM32
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

rusefillc, 2024-01-28:
https://github.com/mck1117/wideband/pull/173#issuecomment-1347375876

Closed 2024-01-26.

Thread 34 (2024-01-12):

Add 2.54mm header while not changing board size

rusefillc, 2024-01-12:
Can not increase board size so would have to do strange stuff - this is all about soldering two boards together with minimal manual effort

technically could be all single 2.54mm pins
technically some pads we can leave without 2.54mm if totally impossible to add

rusefillc, 2024-01-14:
@Ringenium suggests https://www.lcsc.com/product-detail/Connector-Accessories_JST-RT-01T-1-0B-LF_C265321.html instead

rusefillc, 2024-01-16:
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

Ringenium, 2024-01-19:
@rusefillc  добавлено

Closed 2024-01-19.

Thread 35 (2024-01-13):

cost reduction ideas

rusefillc, 2024-01-13:
J2/J3/J4/J5 alternatives same as J10

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

rusefillc, 2024-01-13:
@Qwerty-OFF do we care to use specifically C32677 for "19V 13.3V 12V SOT-23(TO-236) TVS ROHS"

оно basic но относительно дорогой. extended бывают сильно дешевле https://jlcpcb.com/partdetail/Onsemi-MMBZ20VALT1G%2FC153067#EC известный бренд, это подходит?

rusefillc, 2024-01-13:
@Qwerty-OFF усилитель это важно, мы никому тут не верим?

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

Qwerty-OFF, 2024-01-13:
PSM712 можно поменять на другой extended дешёвый PSM712. Твой вариант не подходит

Qwerty-OFF, 2024-01-13:
Усилитель китайский китай брать не стоит, возможно искать какие-то аналоги от нормальных производителей дешевле

rusefillc, 2024-01-28:
> Усилитель китайский китай брать не стоит, возможно искать какие-то аналоги от нормальных производителей дешевле

ну или https://github.com/rusefi/uaefi/issues/40

Closed 2024-01-28.

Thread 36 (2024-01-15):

physically larger pulldown 4.7k-10k on button lines

rusefillc, 2024-01-15:
at the moment button lines pull up/down is done using 0402 which is challenging to adjust manually

we shall add 0603 or better 0805 footprints for button inputs

UAEFI сейчас имеет три входа "button" pullup 10k. Заменяем pullup на 680k, это не сломает работы с обычными кнопками замыкающимися на землю. В адаптере на линиях "button" ставим pulldown 4.7k-10k, за счет этого можно будет использовать данные линии для датчиков/кнопок коммутирующих 12В.

Qwerty-OFF, 2024-01-26:
Какие установить подтяжки в конфигурации по умолчанию?

rusefillc, 2024-01-26:
10k PU 0805
680k PD 0402 на MM?

Qwerty-OFF, 2024-01-28:
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
Сделал 10k 0805 PU в этом поле и 680k 0402 PD внутри MM

Qwerty-OFF, 2024-01-30:
Кажется мы запутались, и нам нужно PU внутри ММ для кнопок замыкающихся на землю, и сильный PD снаружи для более странных кнопок

Qwerty-OFF, 2024-02-05:
Оставляю по умолчанию все button-линии с 0805 pulldown 10k пригодным для использования с кнопками замыкающимися на 12В.

Closed 2024-02-05.

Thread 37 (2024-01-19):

подписать рекомендованные назначения пинов синим

rusefillc, 2024-01-19:
не меняя названия сетей на схеме хочется где-то голубым добавить комментарий про рекомендации

Fan Relay https://rusefi.com/docs/pinouts/hellen/uaefi/?connector=b&pin=B8
Main Relay https://rusefi.com/docs/pinouts/hellen/uaefi/?connector=b&pin=B9
Fuel Pump Relay https://rusefi.com/docs/pinouts/hellen/uaefi/?connector=b&pin=B16
Idle Air Valve https://rusefi.com/docs/pinouts/hellen/uaefi/?connector=b&pin=B18

примерно вот так
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

rusefillc, 2024-01-19:
вторая половина https://github.com/rusefi/kicad6-libraries/issues/15

rusefillc, 2024-01-19:
@Ringenium
VVT1 https://rusefi.com/docs/pinouts/hellen/uaefi/?connector=b&pin=B7
CAM1 https://rusefi.com/docs/pinouts/hellen/uaefi/?connector=c&pin=C5
CAM2 https://rusefi.com/docs/pinouts/hellen/uaefi/?connector=c&pin=C6

Ringenium, 2024-01-19:
Все добавил в компонент

Closed 2024-01-19.

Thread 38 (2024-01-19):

recommended pinout part 2

rusefillc, 2024-01-19:
@Ringenium пожалуйста ещё две голубые рекомендации на uaefi и на футпринт https://github.com/rusefi/rusefi/commit/db7d9057770f254551754dd74fe8b9390423c915

@Qwerty-OFF есть ещё идеи?

Qwerty-OFF, 2024-01-26:
Хочешь на схеме ueafi тоже подписать рекомендованное назначение выводов?

rusefillc, 2024-01-26:
@Qwerty-OFF да!

Qwerty-OFF, 2024-01-28:
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

rusefillc, 2024-01-28:
очевидного решения нет - пока оставим так

Closed 2024-01-28.

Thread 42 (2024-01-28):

ign x6 fuse official work-around

rusefillc, 2024-01-28:
https://github.com/andreika-git/hellen-one/issues/362

Closed 2024-02-05.

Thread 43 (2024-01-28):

ign xX fuse official work-around

rusefillc, 2024-01-28:
https://github.com/andreika-git/hellen-one/issues/362

Closed 2024-01-28.

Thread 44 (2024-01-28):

no current limit on uln2003

rusefillc, 2024-01-28:
See https://github.com/andreika-git/hellen-one/issues/360

rusefillc, 2024-01-28:
let's use VNLD for all low sides both low current and high current

Closed 2024-02-06.

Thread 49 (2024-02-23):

can H/L silk top vs bottom

rusefillc, 2024-02-23:
the silkscreen on uaefi is messed up for CAN labeling
side with stm32 claims H towards the edge of board
bottom claims L is towards edge

Ringenium, 2024-03-01:
@rusefillc ready

Closed 2024-03-27.

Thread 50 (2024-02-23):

rename VR networks

rusefillc, 2024-02-23:
No copper change but let's make schematics more readable

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

vr_1_threshold also looses "_1" since it's the only threshold?

rusefillc, 2024-02-28:
Dup #47

Qwerty-OFF, 2024-03-27:
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

Closed 2024-03-27.

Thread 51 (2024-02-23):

silkscreen on UAEFI mislabels B9 as LSW3, it should be LSW1

ggurov, 2024-02-23:
B9 pin on UAEFI is silkscreened as LSW3 on both sides, it should be LSW1.
 there is now LSW3

Qwerty-OFF, 2024-03-27:
New name is LSH1 (always hot capable)

Closed 2024-03-27.

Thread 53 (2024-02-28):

Add EGT passives into BOM

rusefillc, 2024-02-28:
EGT caps/resistors are probably just a couple of cents? Let's add into BOM

Qwerty-OFF, 2024-03-27:
Only the NUP2105L and MAX31855KASA are DNP now

rusefillc, 2024-03-27:
А можно мы их выключим через replace? мне тогда сильно проще включить при желании

Qwerty-OFF, 2024-03-27:
Да

rusefillc, 2024-08-08:
@Qwerty-OFF какова роль NUP2105L - будет ли без него что-то работать?

если есть шанс жить без него - можно мы на схему что-нить про это напишем?

rusefillc, 2024-08-08:
@dron0gus says ``Элемент защиты. Работать будет.``

Closed 2024-08-15.

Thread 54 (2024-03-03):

make on-board MAP sensor pinout more obvious

rusefillc, 2024-03-03:
a talented individual can solder mpx4250 more than one way, we need some clarification note

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

ggurov, 2024-03-03:
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

rusefillc, 2024-03-03:
I am tired and slow

Just realized that we have a drawing of the vacuum line outlet which tells how to position, not sure if any clarification is needed on top of that.

TIL about notch on the first pin!

ggurov, 2024-03-04:
should mark the input pin. the drawing of the vacuum line did not help. i went for the multimeter to and started tracing stuff. maybe put PC1 next to that through hole for the notch, or  put "notch" next to it as well.

Qwerty-OFF, 2024-03-27:
Added pin numbers
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

Closed 2024-03-27.

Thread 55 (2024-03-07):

WBO stm32f042 has died

rusefillc, 2024-03-07:
On my bench I have uaefi soldered on an adapter board with only +12v, GND and WBO cable connected

* in the beginning I've powered the setup with a (very drained?) battery and things were clicking on start-up
* then I've USB and saw a lot of CAN TX err in main MCU tuner studio
* then I've added +12v to check if start-up would be not clicking
* at some point I've hooked up sensor to the WBO cable

problem: at some point along the way WBO module has died: no blinking, not connecting to st-link

rusefillc, 2024-03-07:
Just assembled another board

Saw red glowing in the corner of stm32f042 while releasing magic smoke.

rusefillc, 2024-03-07:
Adapter board pinout was wrong, see https://github.com/andreika-git/hellen-one/issues/371

Closed 2024-03-07.

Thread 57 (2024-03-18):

pad for resistor between VR lines

rusefillc, 2024-03-18:
* Do we have a pad to mount a resistor between both VR lines?
* is it easy to use?
* do we have a note on the schematics explaining, similar to Frankenso?

rusefillc, 2024-03-23:
@Qwerty-OFF do we already have similar resistor between lines anywhere?

rusefillc, 2024-03-23:
max9924 already has it just needs documentation https://github.com/andreika-git/hellen-one/issues/374

Qwerty-OFF, 2024-03-27:
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

https://github.com/andreika-git/hellen-one/commit/21de8c2cf88dabbff60d48988fd028638cbae64e
https://github.com/andreika-git/hellen-one/commit/48b12a8b670ce0aafff5a7f58c853033d809f7e2

Closed 2024-03-27.

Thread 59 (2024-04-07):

certain UAEFI boards do not initialize 5VP below certain 12v input voltage when they should totally do so cause vehicle batteries can drain lower than that

ggurov, 2024-04-07:
Some uaefi boards (BAD BOARD) seem to not initialize 5VP regulator (GPIO::E10) when voltage is below 11.4 (ish, we ran some tests on one example board). This leads to a NO START condition. If board is connected to USB, 5VP initializes and everything is fine, even below no start threshold voltage. and power keeps on.

Other board examples (GOOD BOARD) will boot down to 6-7v input voltage just fine.

When this board (BAD BOARD) is powered below booting threshold, DFU mode still works, so MCU is alive and powered.

Same board loaded with 407-disco firmware initializes just fine (which is odd, cause GPIO::E10 is something totally not power enable, it's assigned to something in the stepper territory, so may be it just so happens to work.

Anyway, please make UAEFI initialize 5VP more reliably.

rusefillc, 2024-04-07:
@ggurov any more details?

Which revision seems affected? What VBatt does TS show?

Do you have a bad board in NJ? What the minimal set of wires to reproduce the issue?

ggurov, 2024-04-07:
not sure about revision, we will check and record this.

minimal set of wires is 2-3:

1 ground
2 vign (if only this is hooked up, it raises the threshold, and board is worse at booting at lower voltages )
3 +12v main (forget what this is called) - if this is hooked up in addition to vign, board will init at lower voltage.

i do not have a power supply that can adjust below 11.6 or so, completely avoiding this. i may look into finding a 9v power brick to test my boards with.

when the board does not boot, COM port does not initialize, and TS will not connect. BUT DFU can be entered with buttons.

when the board does not boot, PE10 (en for U411 secondary regulator) stays low, when the board boots, that's at 3.3v.

when the board does not boot, 5VP led stays off.

ggurov, 2024-04-07:
both test boards are revA, one is bad, one is good

rusefillc, 2024-04-07:
@ggurov please confirm lack of capacitors next to SD as in https://github.com/andreika-git/hellen-one/issues/353

rusefillc, 2024-04-07:
See also #25

ggurov, 2024-04-07:
problem with looking at Vbat is usb connection will initialize the MCU making it turn 5VP on.

we did a test with a usb cable that does  not have power connected, good board would initialize and report to TS down to 4.4 volts, bad board would not initialize below 11.4 or so.

ggurov, 2024-04-07:
but the bad board could enter DFU via the same powerless usb cable below threshold

ggurov, 2024-04-09:
bad board, running disco firmware initializes.

however, if we assign E10 to lets say "main relay", and below about 12.6v turn that on, the board goes offline.

so something is messed up with 5VP regulator, since turning it on causes MCU to go offline.

rusefillc, 2024-04-11:
3v goes away, time to replace TLS115?

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

ggurov, 2024-04-11:
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

5v bridge to EN on tls115 external 5v regulator,  (5v to pin 7)

a fix has been proposed and tested for basic functionality
https://rusefi.com/forum/viewtopic.php?f=4&t=2748

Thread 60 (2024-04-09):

hold on we forgot about SPI for TLE9201?

rusefillc, 2024-04-09:

Qwerty-OFF, 2025-04-30:
You may not have used it yet when we did this. If we remove the green and yellow LEDs, there should be enough pins for this functionality.

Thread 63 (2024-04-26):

alternative/nicer connector + enclosure combo

rusefillc, 2024-04-26:
Molex is not ideal.

What better connector + enclosure combo shall we use?

As is I belive uaEFI has 68 pins

rusefillc, 2024-04-26:
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

stwillocks, 2024-05-08:
from Facebook post:

 90 pin enclosure from AliExpress: 90 Pin Way Car Driving Computer Board ECU Aluminum Box Housing PCB Socket Plug For Small Siemens Car AS90-1 211PC902S0008
 https://www.aliexpress.us/item/1005002745770669.html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

 Matching road car unit that I found is:

 S110140002 RENAULT CLIO EMS3132, 8200326391, 8200326380

It needs confirmation. The clio one is seems little bigger as enclosure.

rusefillc, 2024-08-14:
that's https://github.com/rusefi/rusefi/wiki/uaefi121 or maybe uaefi90 later

Closed 2024-08-14.

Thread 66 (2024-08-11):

how to i hook up logic analyzer to both VRs?

rusefillc, 2024-08-11:
We have amazing "cam" and "crank" vias on MM100 but looks like these are routed into random hall/button inputs?

Q1: where are the best spots to solder a wire for logic analyzer?
Q2: do we have space on the board to add vias?

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

rusefillc, 2024-08-11:
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

Qwerty-OFF, 2024-08-14:
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

Closed 2024-08-14.

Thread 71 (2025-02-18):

Hellen-one mega MCU input filter caps not matching

P4ulBr4ndt, 2025-02-18:
C202 is 10nF vs 200, 201 and 203 1nF is probably not intentional? Or maybe it is and I don't get it
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
When building hellen-one boards it gets like this into BoM and is manufactured like this

rusefillc, 2025-02-18:
@P4ulBr4ndt what does https://github.com/rusefi/uaefi/blob/main/bom_pullups_uaefi-d.csv have?

rusefillc, 2025-02-18:
@Qwerty-OFF is this a usability issue - shall we mention "see pullups replacement file for actual values" on all relevant pages?

P4ulBr4ndt, 2025-02-18:
As a user I can report bom_replace file feels more documented then pullups replacement file.
Might want to add it to hellen-one docs more?
Also for the defaults maybe its still nice to have them matching 🤔

Qwerty-OFF, 2025-04-30:
Only in mm-100 for now
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

Closed 2025-04-30.

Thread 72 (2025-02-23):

report of unit damaged by +12v into hall input

rusefillc, 2025-02-23:
*unit has passed HW QC
* unit was shipped to customer
* MCU is now dead
* user says +12v into hall input XXX

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

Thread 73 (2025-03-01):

nissan 76 pinout

rusefillc, 2025-03-01:
101 inj 1
12 ign 4
12 ign 2
11 ign 6
116 inj gnd
110 inj 5
3 ign 3
2 ign 5
1 ign 1
103 inj 3
16 eccs relay
18 fuel pump relay
112 inj 6
113 vvt solenoid
105 inj 2
114 inj 4
23 knock
58 12v battery
26 afm gnd
28 clt sensor
30 sensor gnd
45 ign switch
56 TPs signal
38 5v TPs
50 ecu gnd
51 crank sensor 120
52 crank sensor 1

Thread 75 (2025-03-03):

Uaefi ecu secondary serial error

ozeromer1111, 2025-03-03:
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

In the hardware drawing of the circuit, PD5 PD6 is designated as rx/tx pins. I cannot establish serial communication using these pins. when i try to connect using a ttl converter i fail

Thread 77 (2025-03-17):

quality issue: report of bad internal MAP trace

rusefillc, 2025-03-17:

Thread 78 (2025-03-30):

switch to SN74LXCH8T245PWR

rusefillc, 2025-03-30:
See https://github.com/andreika-git/hellen-one/issues/378#issuecomment-2764559502 does this seem smart and wise?

rusefillc, 2025-07-31:
new part LXH8T245

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

old part

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

rusefillc, 2025-09-21:
positive feedback see https://rusefi.com/forum/viewtopic.php?p=50894#p50894

Closed 2025-04-30.

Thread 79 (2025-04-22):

migrate to power_12and5V 0.3 to get RTC working

rusefillc, 2025-04-22:
See https://github.com/andreika-git/hellen-one/issues/398

rusefillc, 2025-04-22:
PS: software progress would be needed as well https://github.com/rusefi/rusefi/pull/7299

Closed 2025-04-30.

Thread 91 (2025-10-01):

uaEFI + uaDASH + dash sweep script we get CAN TX failure on simultaneous power up

rusefillc, 2025-10-01:
uaefi with dash-sweep.lua script
uaDASH7
lab power supply
no USB

power on

actual result: no activity on dash

if we hook USB and connect with TS, we see CAN TX ERR going up on ECU side

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

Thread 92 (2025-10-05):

any analog inputs we can use as pull-down around 500K event input pin?

rusefillc, 2025-10-05:
looking for piggy-back hall event input with weak pull down, do we have any/couple of options?

Qwerty-OFF, 2025-10-05:
Try D1 and C15

rusefillc, 2025-10-05:
https://rusefi.com/docs/pinouts/hellen/uaefi/?connector=d&pin=D1

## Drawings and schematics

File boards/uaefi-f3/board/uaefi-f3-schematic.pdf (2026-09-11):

IN3 Ignition OUT3 OUT2 OUT1 | IN1
uSD card and accelerometer on SPI1 bus | Barometer on this I2C bus F40x does not have UART8

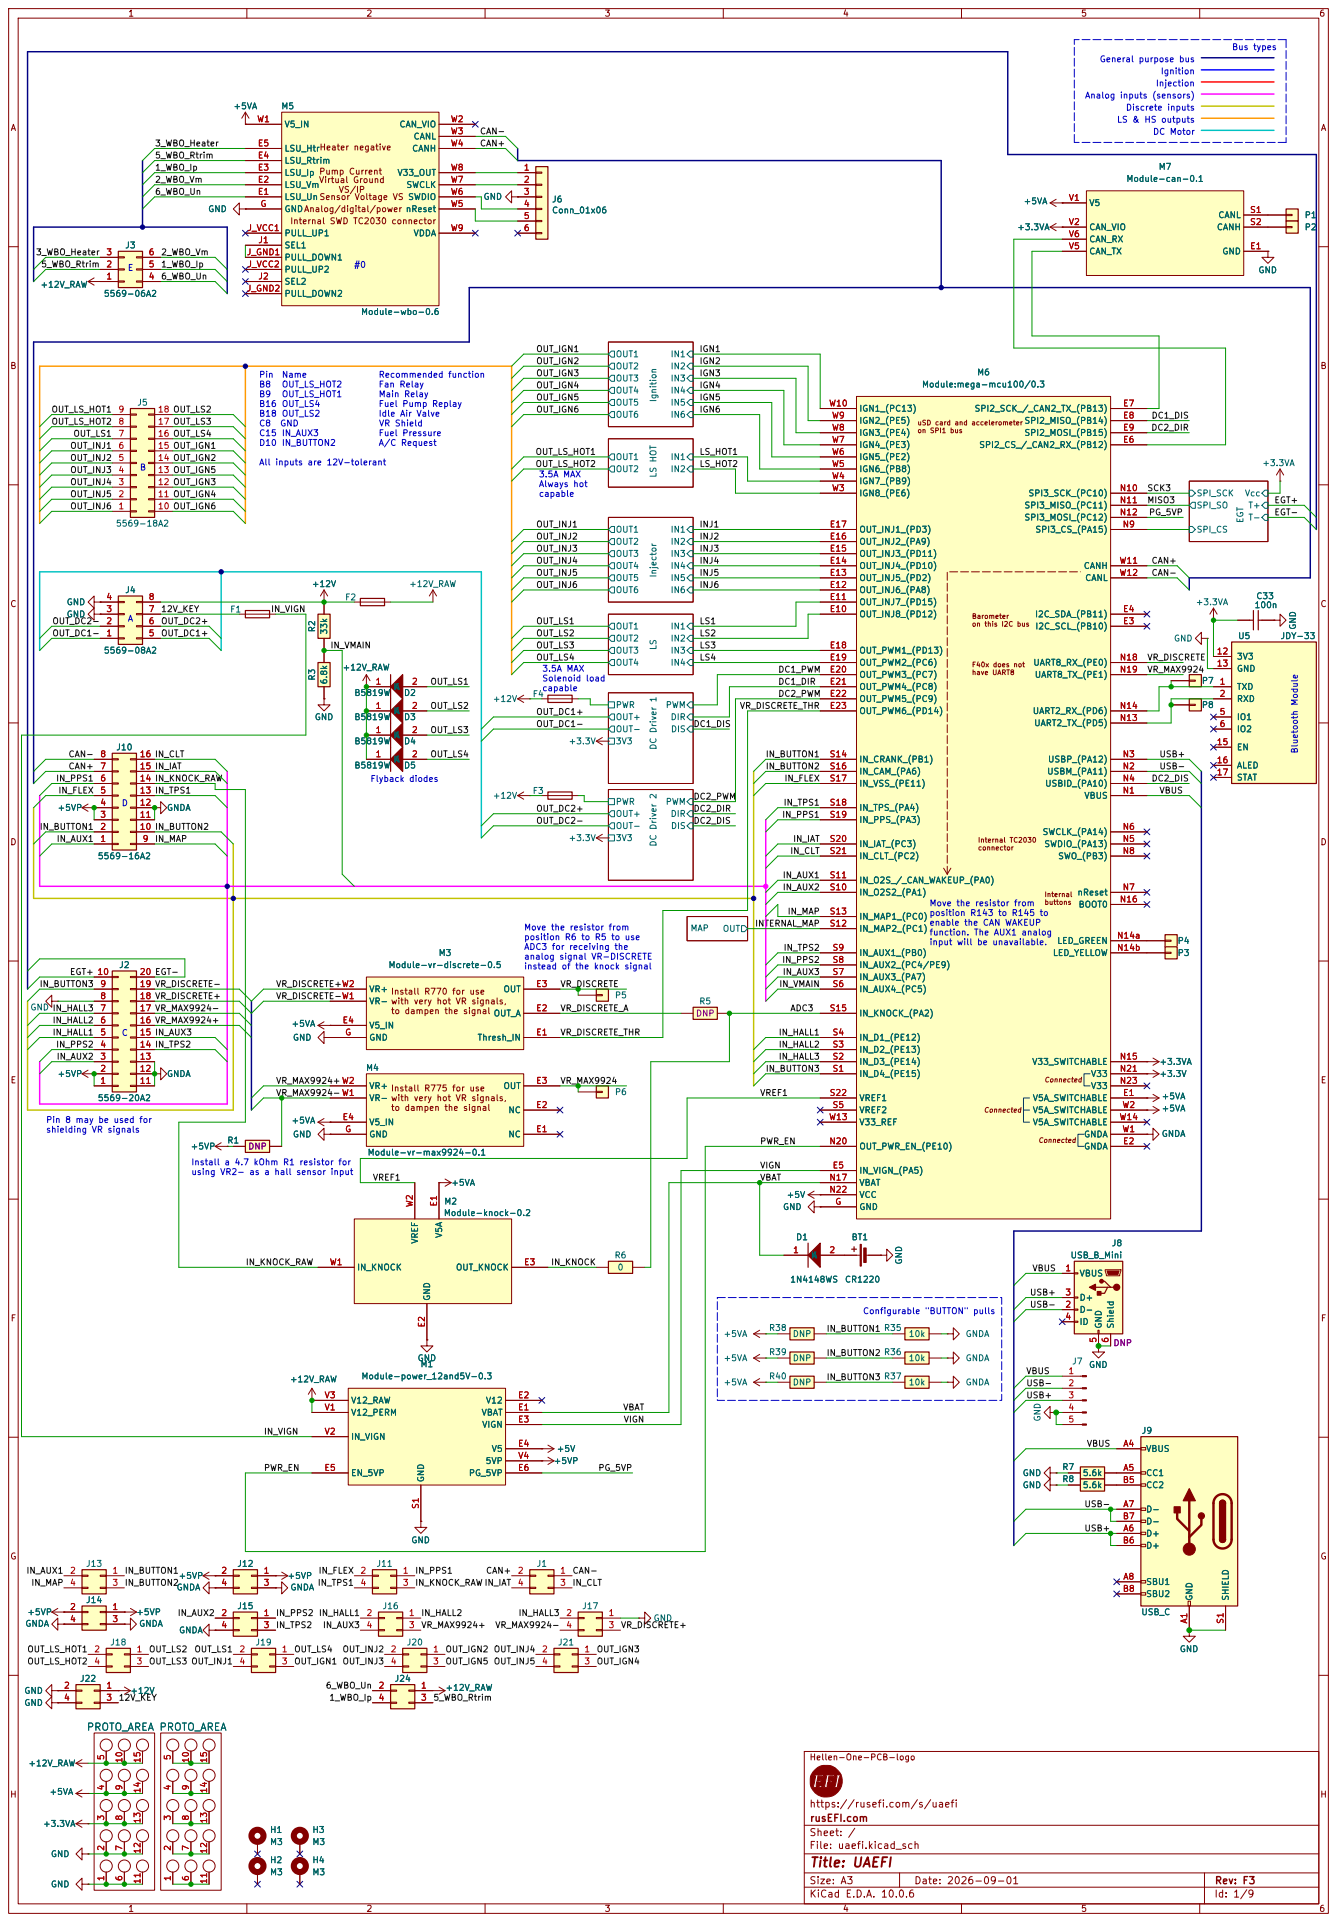
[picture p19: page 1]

Injection General purpose bus

Analog inputs (sensors) LS & HS outputs Discrete inputs

Internal SWD TC2030 connector Sensor Voltage VS Heater negative

Analog/digital/power Virtual Ground

OUT_INJ1
OUT_INJ2 OUT_INJ6
Always hot capable Pin 8 may be used for shielding VR signals

Move the resistor from
position R143 to R145 to
enable the CAN WAKEUP
function. The AUX1 analog

position R6 to R5 to use ADC3 for receiving the analog signal VR-DISCRETE

instead of the knock signal

Install R770 for use with very hot VR signals,

Install R775 for use with very hot VR signals,

Install a 4.7 kOhm R1 resistor for using VR2- as a hall sensor input

Hellen-One-PCB-logo

https://rusefi.com/s/uaefi
rusEFI.com
Sheet: /
File: uaefi.kicad_sch
Title: UAEFI
KiCad E.D.A. 10.0.6

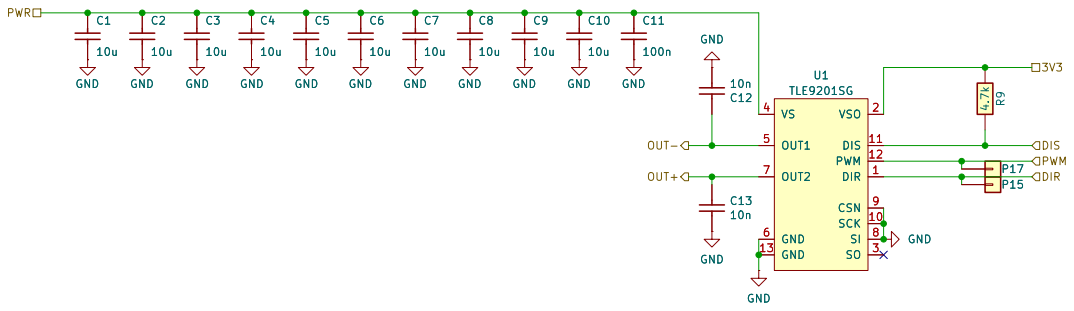
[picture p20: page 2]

SCK 10 DIS 11 PWM 12 GND 13 GND

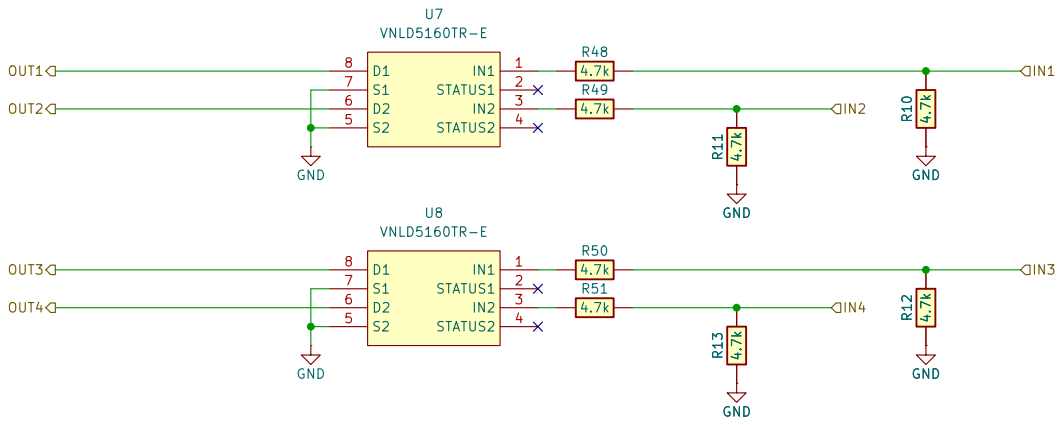
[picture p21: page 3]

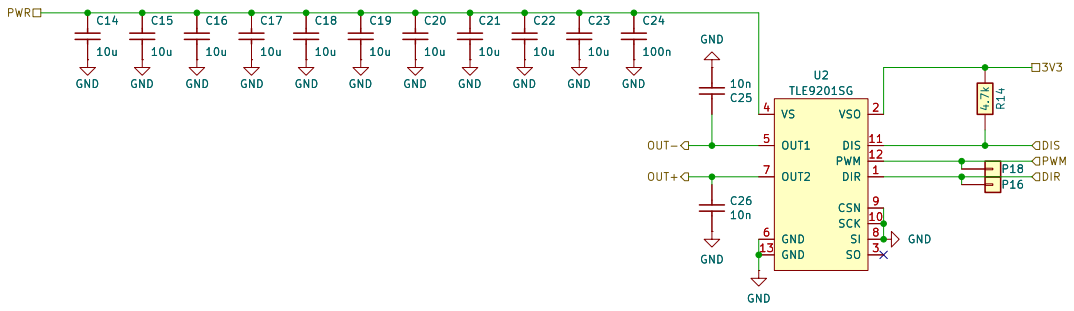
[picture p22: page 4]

SCK 10 DIS 11 PWM 12 GND 13 GND

Vcc SPI_SO
rusEFI.com GND

NUP2105L is optional, used for protection D8NUP2105L ³

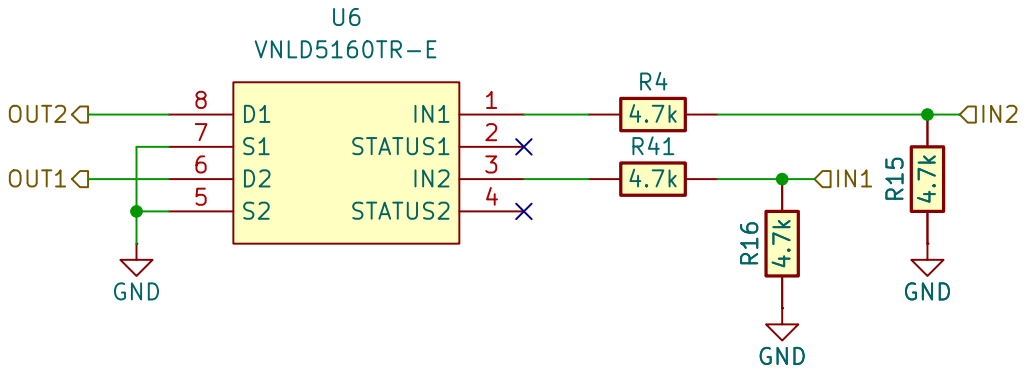
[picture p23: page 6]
D Date: 2026-07-14; Size: A4; Rev: F3; GND R15 4.7k GND GND R16 4.7k; IN1 1 STATUS1 2 IN2 3 STATUS2 4; VNLD5160TR-E; IN2 OUT1; IN1 OUT2; R16 4.7k GND; GND R15 4.7k

rusEFI.com
Sheet: /LS HOT/
File: LS_HOT.kicad_sch
Title: UAEFI
KiCad E.D.A. 10.0.6

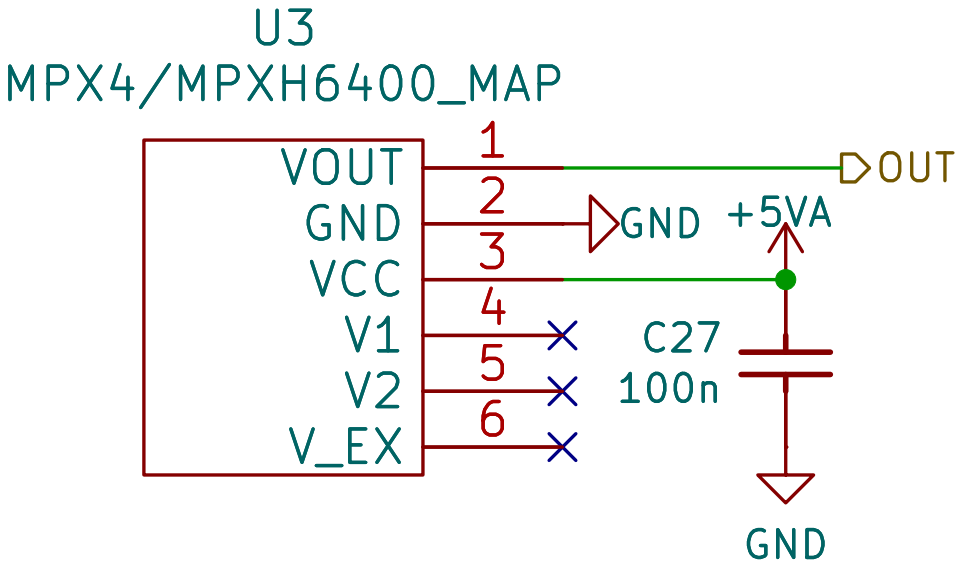
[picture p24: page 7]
D Date: 2026-07-14; KiCad E.D.A. 10.0.6; Size: A4; Rev: F3; Title: UAEFI; File: MAP.kicad_sch; Sheet: /MAP/; rusEFI.com; VOUT; GND; VCC; U3 MPX4/MPXH6400_MAP; GND +5VA C27; OUT U3; MPX4/MPXH6400_MAP

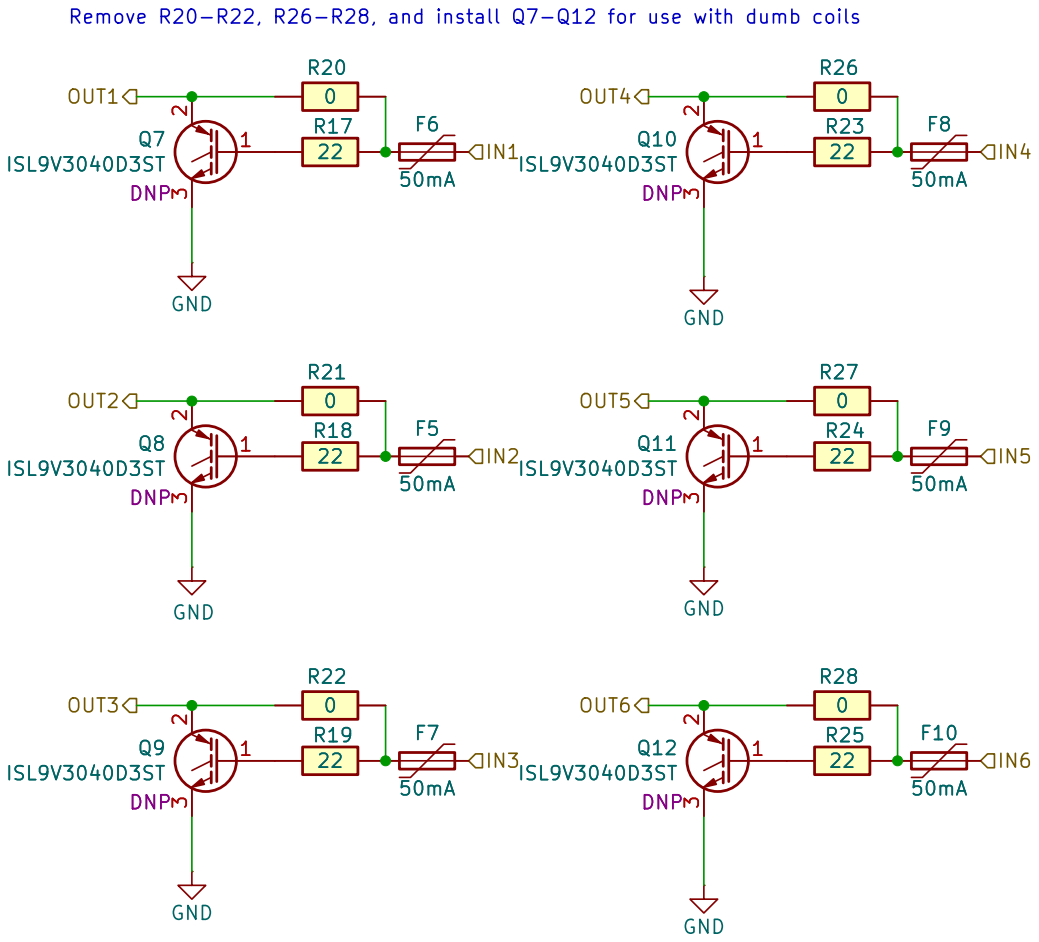
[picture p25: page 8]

IN1 Remove R20-R22, R26-R28, and install Q7-Q12 for use with dumb coils R21

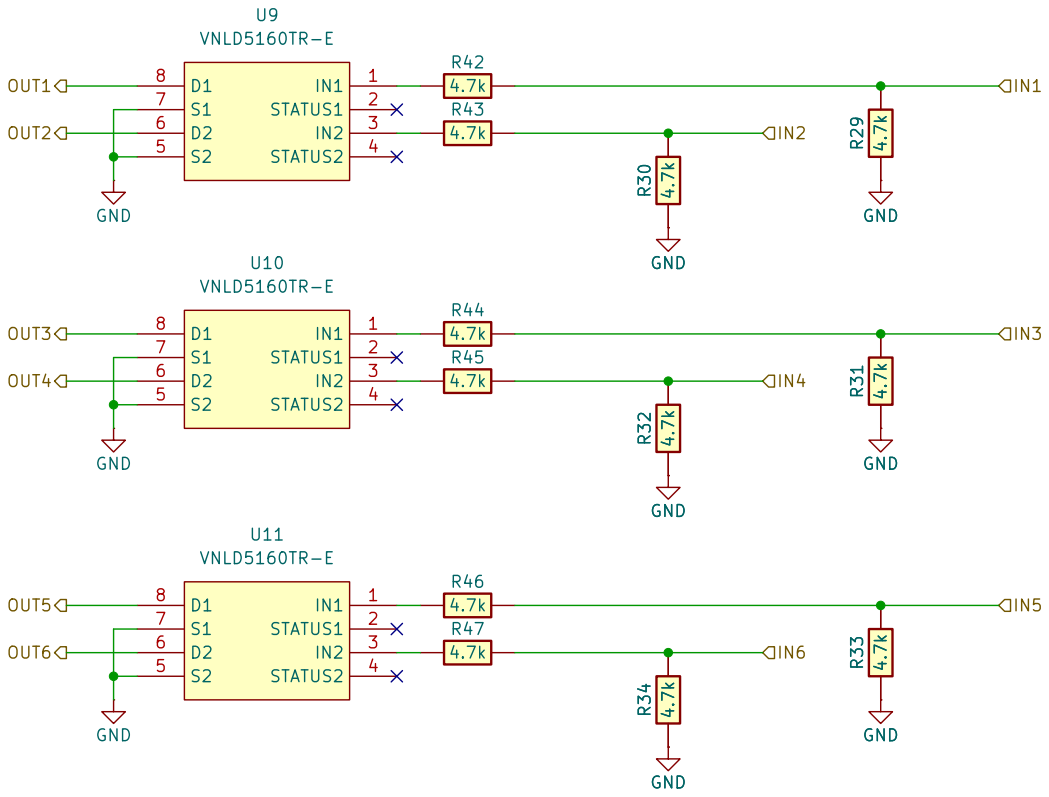
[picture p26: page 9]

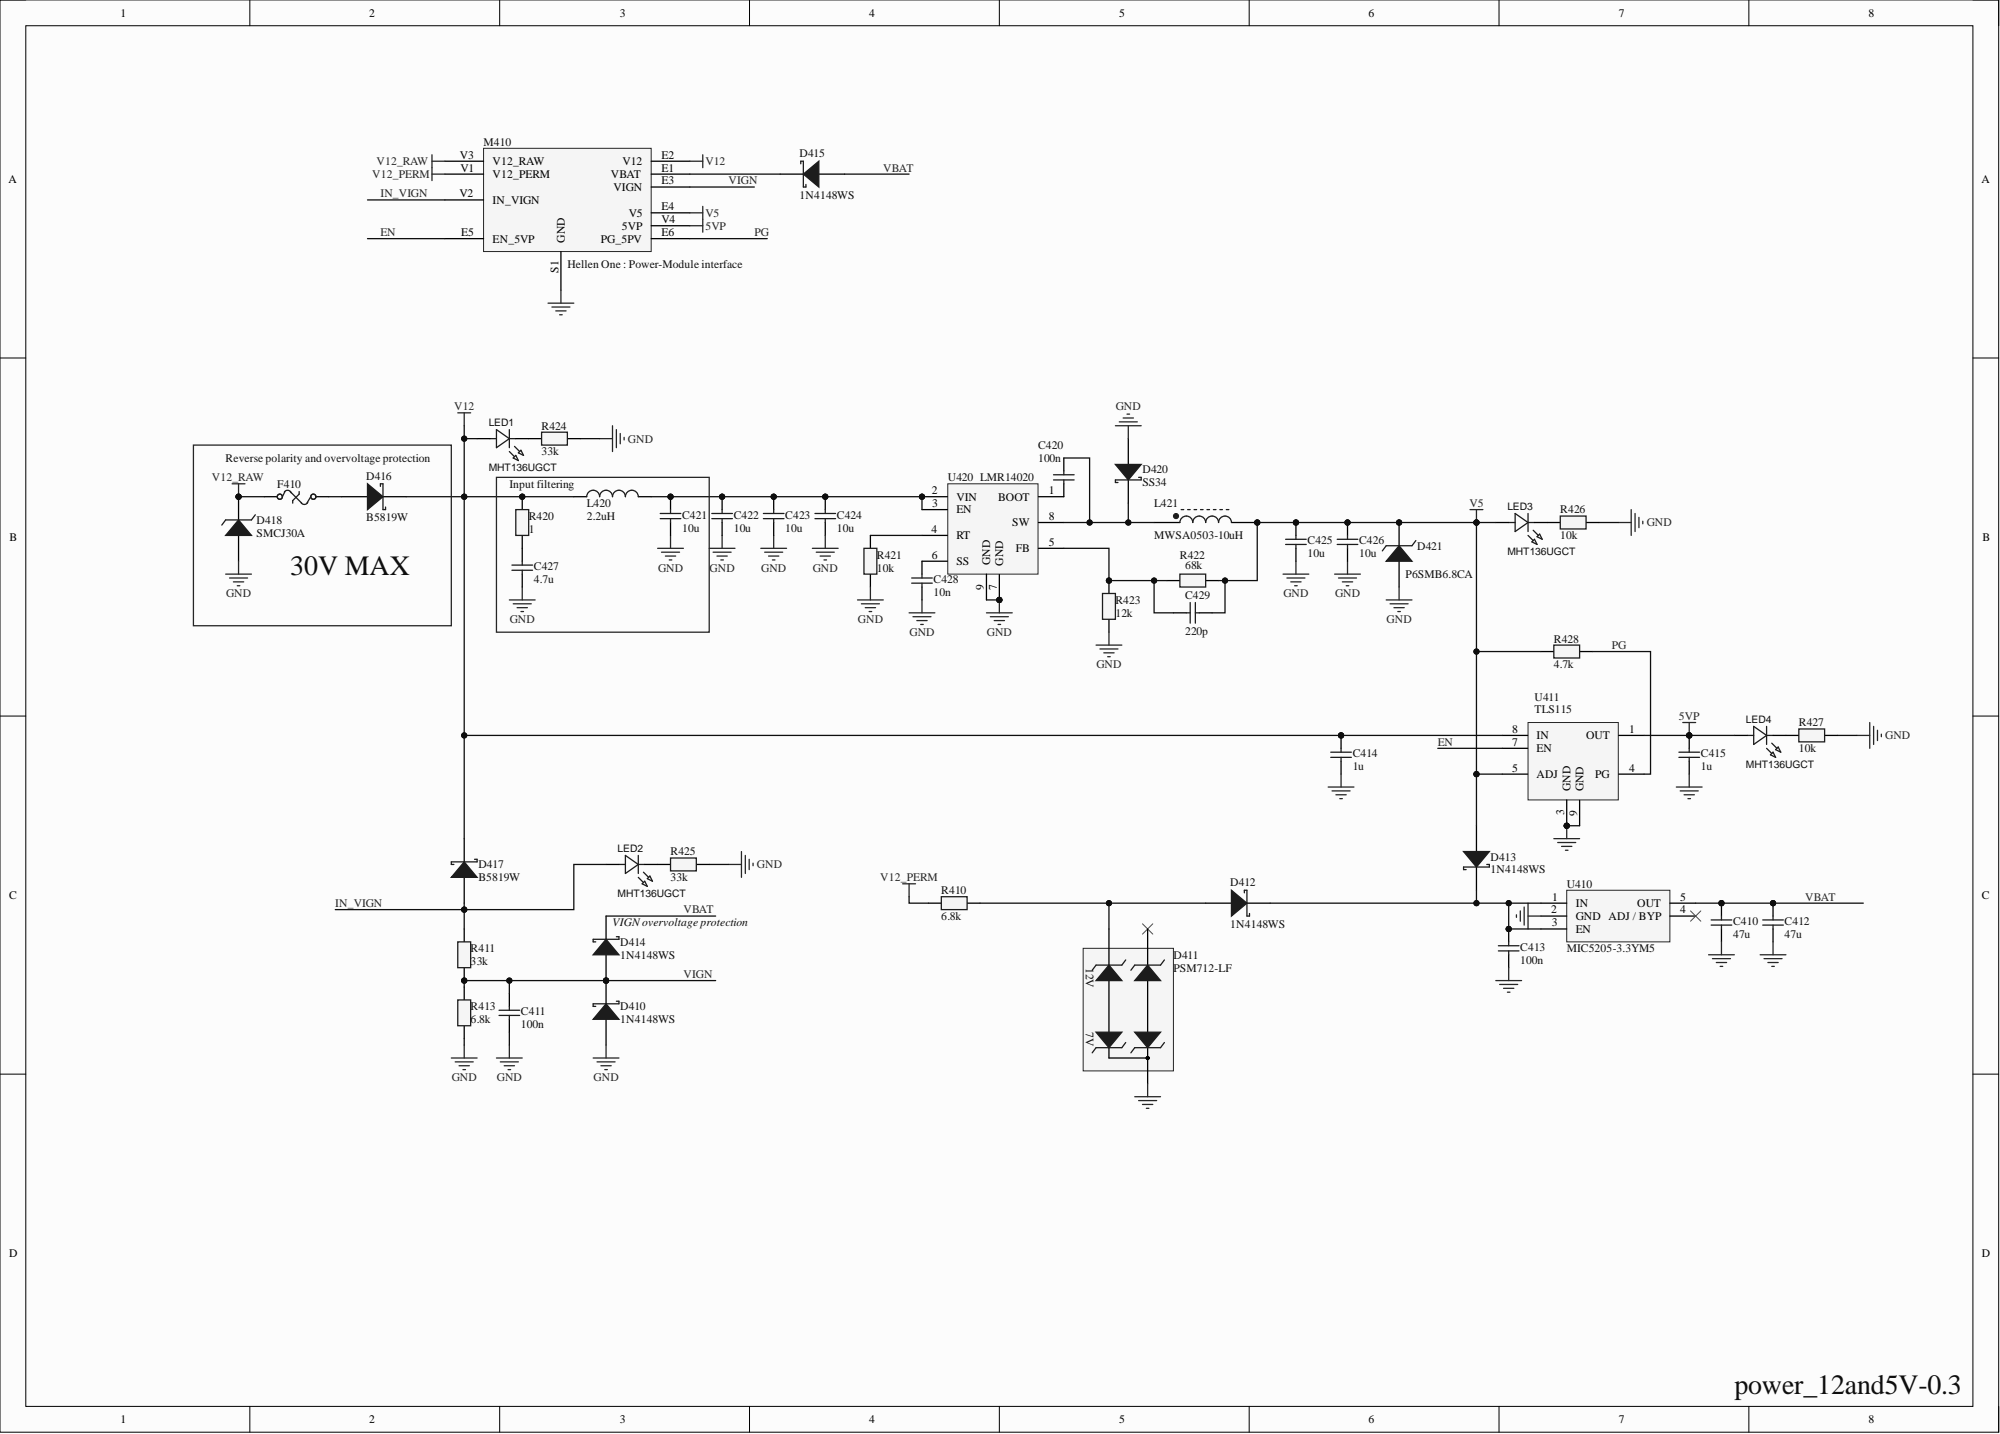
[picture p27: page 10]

Hellen One : Power-Module interface

Reverse polarity and overvoltage protection
F410 V12_RAW

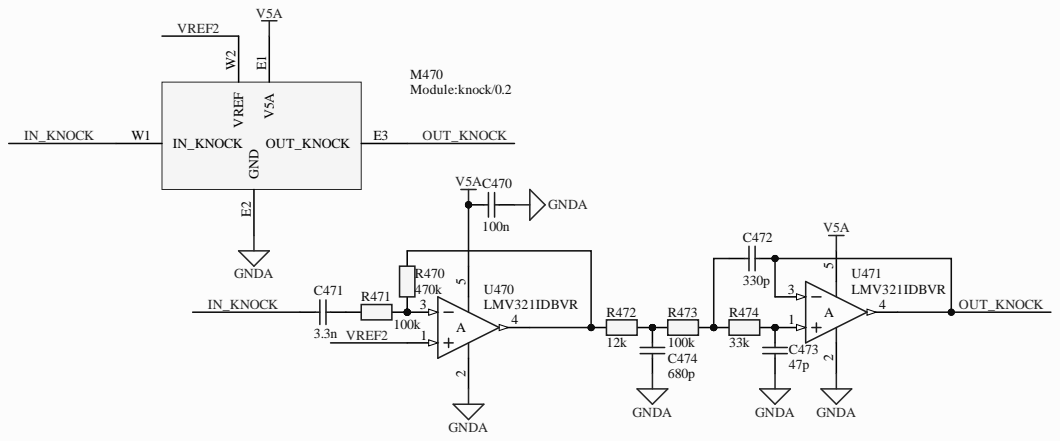
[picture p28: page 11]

# 6 U751 GND

1u R761

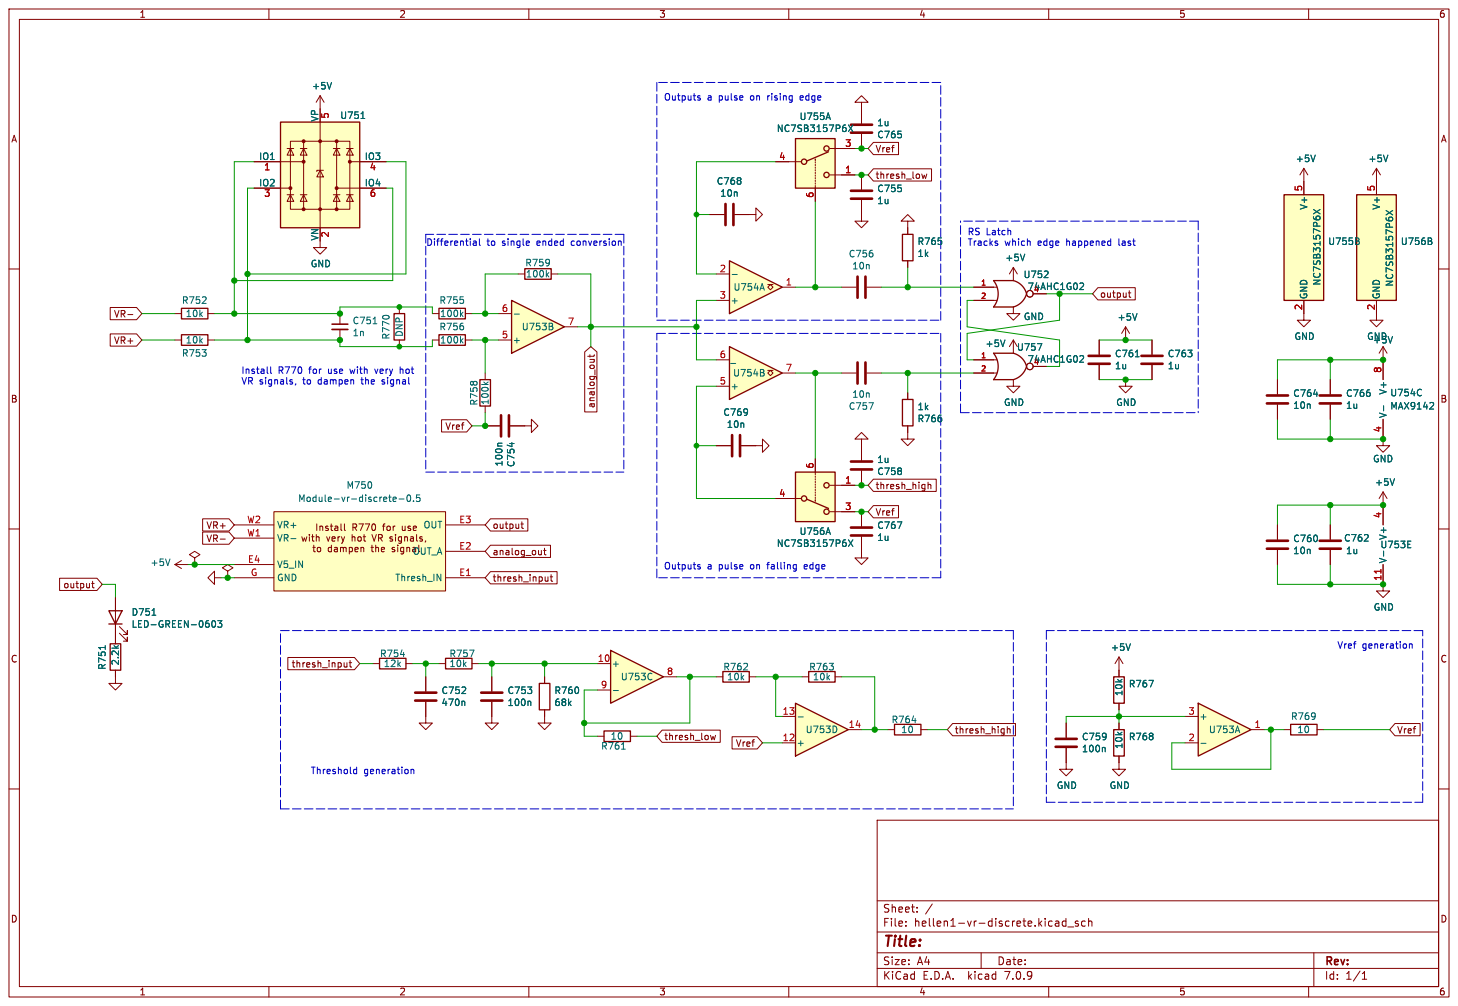
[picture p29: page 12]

Id: 1/1 Title: File: hellen1-vr-discrete.kicad_sch Sheet: /

File: hellen1-vr-max9924.kicad_sch Sheet: /
Id: 1/1 Title: VR MAX9924 module

33n R604

# 100n GND

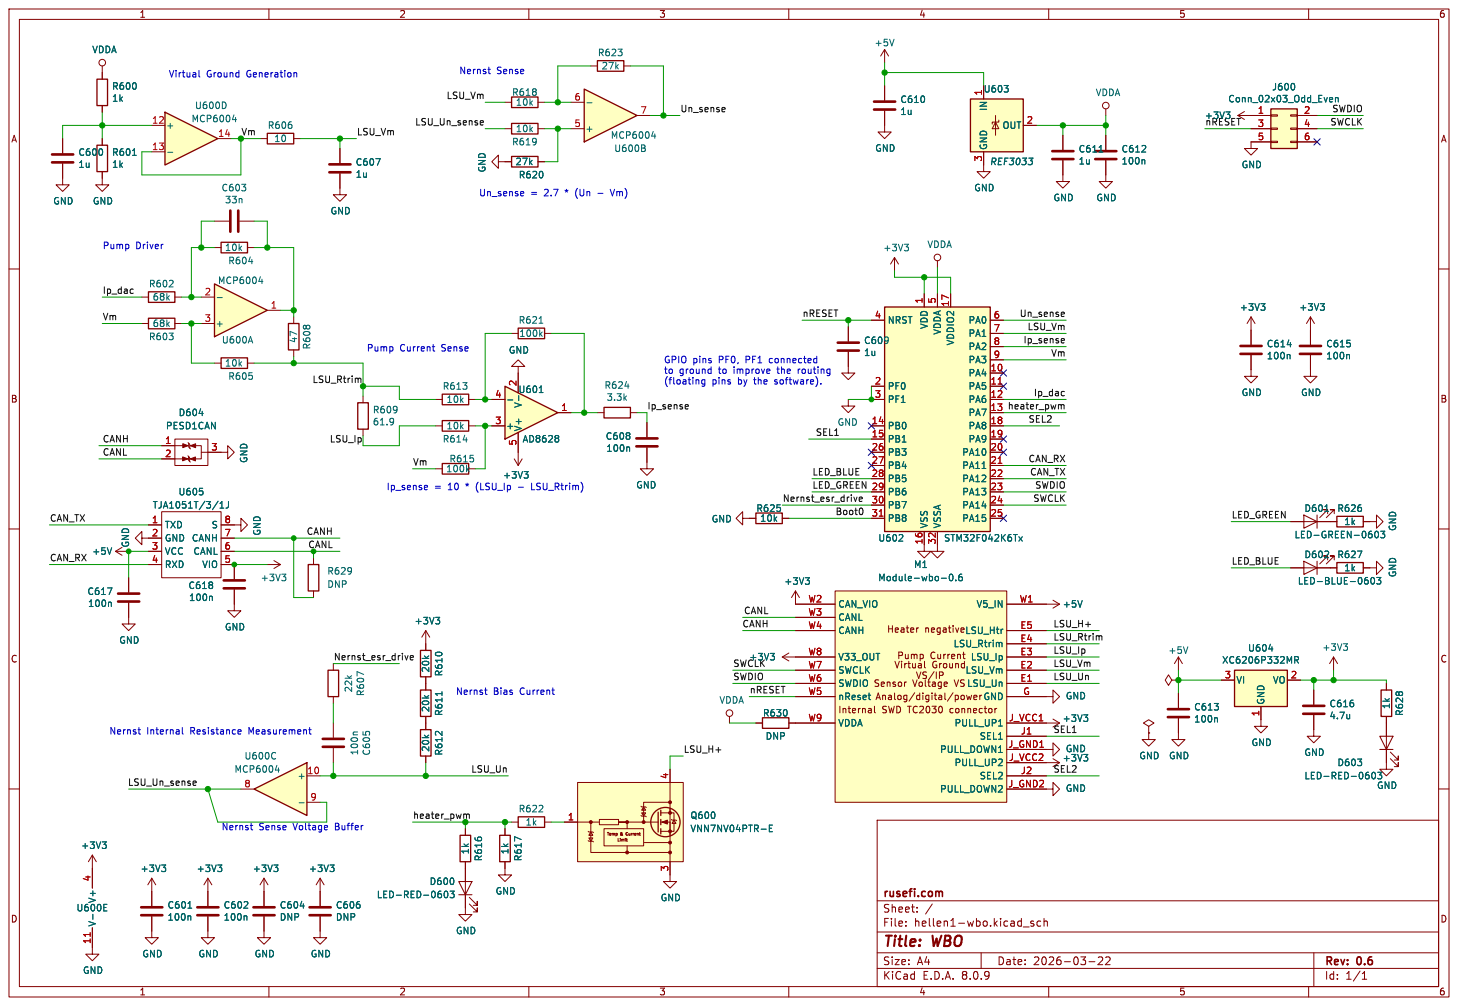
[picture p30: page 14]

1 PA4 10 PA5 11 PA6 12 PA7 13 PB0 14 PB1 15 VSS 16 VDDIO2 17 PA8 18 PA9 19 PF0 2 PA10 20 PA11 21 PA12 22 PA13 23 PA14 24 PA15 25 PB3 26 PB4 27 PB5 28 PB6 29 PF1 3 PB7 30 PB8 31 VSSA 32 NRST 4 VDDA

to ground to improve the routing

File: hellen1-wbo.kicad_sch Sheet: / rusefi.com

Vdd 4; Vss 6; MCP6004; GNDA; OUT1; OUT2; OUT3; OUT4

Vdd 4; Vss 6; MCP6004; GNDA; OUT1; OUT2; OUT3; OUT4

Vdd 4; Vss 6; MCP6004; GNDA; OUT1; OUT2; OUT3; OUT4; C190 PIC19001 100n; PIC19002 COC3; PIR19001; PIR19002; PIR19003; PIR19004; PIR19005; PIR19006; PIR19007; PIR19008; COR5; PIR19101; PIR19102; PIR19103; PIR19105; PIR19104; PIR19106; PIR19107; PIR19108; COR6; PIU19001; PIU19002; PIU19003; PIU19004; PIU19005; PIU19006; PIU19007; PIU19008; PIU19009; PIU190010; PIU190011; PIU190012; PIU190013; PIU190014; COU2; PIC19001; POOUT2; POOUT1; POOUT3; POOUT4; POIN1; POIN3 PIU19005; PIU190010 POIN4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


R143 populated: analog input O2S
R145 populated: WAKEUP by CAN

*VIGN input is unprotected!
*A21 is duplicated for ADC and EINT


See pullups replacement file for actual values


# See pullups replacement file for actual values


0 PESD; VCC; 5 RXD; 6 CANH

USBM USBP USBID VBUS
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

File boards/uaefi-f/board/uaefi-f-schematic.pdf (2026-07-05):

3V3 | DC Driver 1 OUT5
nReset | W5 SWDIO | W6 SWCLK | W7 V33_OUT | W8 VDDA | W9 M5 | Module-wbo-0.6 K


LS & HS outputs DC Motor General purpose bus

T- T+ EGT
3V3 12 GND 13 EN 15 ALED 16 STAT 17 RXD 2

enable the CAN WAKEUP
input will be unavailable.

analog signal VR-DISCRETE
instead of the knock signal

https://rusefi.com/s/uaefi-pro
Id: 1/9 Title: UAEFI File: uaefi.kicad_sch Sheet: / rusEFI.com



Id: 3/9 Title: UAEFI File: LS4.kicad_sch Sheet: /LS/ rusEFI.com

D Date: 2026-07-05 KiCad; E.D.A. 8.0.9 Size: A4; Rev:; Id: 6/9 Title: UAEFI File: LS_HOT.kicad_sch Sheet: /LS; HOT/ rusEFI.com; GND R¹⁵ 4.7k GND; GND R¹⁶ 4.7k; 1 STATUS1; 3 STATUS2; U6 VNLD5160TR-E; IN2 OUT1; IN1 OUT2; R¹⁶ 4.7k GND; GND R¹⁵ 4.7k

D Date: 2026-07-05 KiCad; E.D.A. 8.0.9 Size: A4; Rev:; VOUT; 1 GND; 2 VCC; 6 U3 MPX4/MPXH6400_MAP; GND GND; OUT U3 MPX4/MPXH6400_MAP

Id: 8/9 Title: UAEFI File: MAP.kicad_sch Sheet: /MAP/ rusEFI.com


Id: 9/9 Title: UAEFI File: IGN6.kicad_sch Sheet: /Ignition/ rusEFI.com


1 T- 2 T+ 3 V_{CC} 4 SCK 5 ~{CS}6 SO 7 C32

1 T- 2 T+ 3 V_{CC} 4 SCK 5 ~{CS}6 SO 7 U4 MAX31855KASA

Id: 9/9 Title: UAEFI File: egt.kicad_sch Sheet: /EGT/ rusEFI.com GND


Hellen One : Power-Module interface

Reverse polarity and overvoltage protection
F410 V12_RAW


# 6 U751 GND

1u R761


Id: 1/1 Title: File: hellen1-vr-discrete.kicad_sch Sheet: /


File: hellen1-vr-max9924.kicad_sch Sheet: /
Id: 1/1 Title: VR MAX9924 module

33n R604

# 100n GND


1 PA4 10 PA5 11 PA6 12 PA7 13 PB0 14 PB1 15 VSS 16 VDDIO2 17 PA8 18 PA9 19 PF0 2 PA10 20 PA11 21 PA12 22 PA13 23 PA14 24 PA15 25 PB3 26 PB4 27 PB5 28 PB6 29 PF1 3 PB7 30 PB8 31 VSSA 32 NRST 4 VDDA

to ground to improve the routing

File: hellen1-wbo.kicad_sch Sheet: / rusefi.com

Vdd 4; Vss 6; MCP6004; GNDA; OUT1; OUT2; OUT3; OUT4

Vdd 4; Vss 6; MCP6004; GNDA; OUT1; OUT2; OUT3; OUT4

SPI_; VCC; 5 SPI_SCK; 7 SPI_O; lex MicroSD; _MIS


R143 populated: analog input O2S
R145 populated: WAKEUP by CAN

*VIGN input is unprotected!
*A21 is duplicated for ADC and EINT


See pullups replacement file for actual values


# See pullups replacement file for actual values


VRE; _CRA; _CLT; IAT; _IAT; VIG; nRes; VBAT; SWCL; SPI2; _MIS; SPI3; I2C_SCL; SPI1; PWR_; GRE; u mcu.Sch; _IGN; 8.Sch; _can can.Sch; d.Sch; nRS; USB_; P USB_; USBI; A I2C_SCL UART8_RX UART8_TX UART2_RX UART2_TX; N VBAT; VCC; ACC_SC; ACC_; ACC_MIS; ACC_MO; BARO; sen; ors.Sc; LVC1; VBU; wer.Sch; USBID (PA; USBM (PA; USBP (PA; 8 SWDIO (PA13); N5 SWCLK (PA14); N6 nReset; _SCK (PC1; _MISO (PC1; _MOSI (PC1; I2C_SCL (PB1; 3 I2C_SDA (PB11); E4 UART2_TX (PD5); _SCK; _MISO (PB1; _MOSI (PB1; _PWM2 (PC6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

USBM USBP USBID VBUS

### COR2

Vdd 4; Vss 6; MCP6004; GNDA; IN1 (CRNK); OUT1; OUT2; OUT3; OUT4; C195 PIC19501 100n; PIC19502 COC2; PIR19502; PIR19501; PIR19601; PIR19602; PIR19603; PIR19604; PIR19605; PIR19606; PIR19607; PIR19608; COR3; PIR19701; PIR19702; PIR19703; PIR19705; PIR19704; PIR19706; PIR19707; PIR19708; COR4; PIU19501; PIU19502; PIU19503; PIU19504; PIU19505; PIU19506; PIU19507; PIU19508; PIU19509; PIU195010; PIU195011; PIU195012; PIU195013; PIU195014; COU1; PIC19501; POOUT1; POOUT2; POOUT3; POOUT4; POIN1 (CRNK)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

More accurate threshold for "raw" connection of VR sensors


RES 5; GND(1) 6; GND(2); 7 GND(3); 8 VDD; 9 VDD_IO; INT_2 11; INT_1 12; U106 LIS2DH12TR; VDD 10; INT DRDY; RES 3; Vdd IO 1; GND; LPS22HBTR; ACC_SCK ACC_CS ACC_MISO ACC_MOSI; BARO_SCL BARO_SDA

SCL/SPC 1
SDO/SA0 3
SDA/SDI/SDO 4

SCL/SPC 2
SDO/SA0 5

andreika; Size:; Author:; Date:; Revision:; Sheet; PESD1CAN; GND; CANH; CANL; TXD 1 GND 2 VCC 3; Vio; 5 RXD 4; 6 CANH; TJA1051T/3/1J; CANH CANL; CAN_TX; CAN_RX; CAN_VIO; CAN_VIO V2; S2 CANL; CAN_TX V5; CAN_RX V6; Module:can/0.1

Hellen-One CAN
Title:

rusEFI EMS
Hellen-One Platform
https://rusefi.com/s/hellen72

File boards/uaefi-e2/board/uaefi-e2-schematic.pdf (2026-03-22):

# IN3 LS OUT5

IGN1_(PC13) W10 | CANH | W11 CANL | W12 V33_REF W13 | V5A_SWITCHABLE W14 V5A_SWITCHABLE | W2


CAN-
3V3 12 GND 13 EN 15 ALED 16 STAT 17 RXD 2

enable the CAN WAKEUP

input will be unavailable. C

analog signal VR-DISCRETE
instead of the knock signal

Hellen-One-PCB-logo

https://rusefi.com/s/uaefi
Id: 1/9 Title: UAEFI File: uaefi.kicad_sch Sheet: / rusEFI.com


D Date: 2025-04-30 KiCad; E.D.A. 8.0.9 Size: A4; Rev:; GND GND; GND R¹² 4.7k R¹¹ 4.7k GND GND; R¹³ 4.7k; 1 STATUS1; 3 STATUS2; U7 VNLD5160TR-E; U8 VNLD5160TR-E; R¹⁰ 4.7k GND; IN2 OUT1; IN4 OUT3 OUT2 OUT4; R¹⁰ 4.7k GND GND R¹³ 4.7k GND R¹¹ 4.7k; R¹² 4.7k GND

Id: 3/9 Title: UAEFI File: LS4.kicad_sch Sheet: /LS/ rusEFI.com

D Date: 2025-04-30 KiCad; E.D.A. 8.0.9 Size: A4; Rev:; Id: 6/9 Title: UAEFI File: LS_HOT.kicad_sch Sheet: /LS; HOT/ rusEFI.com; GND R¹⁶ 4.7k GND; R¹⁵ 4.7k; 1 STATUS1; 3 STATUS2; U6 VNLD5160TR-E GND; IN2 OUT1 OUT2; R¹⁵ 4.7k GND R¹⁶ 4.7k; GND

D Date: 2025-04-30 KiCad; E.D.A. 8.0.9 Size: A4; Rev:; VOUT; 1 GND; 2 VCC; 6 U3 MPX4/MPXH6400_MAP; GND GND; OUT U3 MPX4/MPXH6400_MAP

Id: 8/9 Title: UAEFI File: MAP.kicad_sch Sheet: /MAP/ rusEFI.com


Id: 9/9 Title: UAEFI File: IGN6.kicad_sch Sheet: /Ignition/ rusEFI.com


Id: 9/9 Title: UAEFI File: egt.kicad_sch Sheet: /EGT/ rusEFI.com GND

6 ABCD; ABCD Date: 2025-04-30 KiCad; E.D.A. 8.0.9 Size: A4; Rev:; Id: 10/9 Title: UAEFI File: INJ6.kicad_sch Sheet: /Injector/ rusEFI.comR³³ 4.7k GND R³⁴ 4.7k GND GND R³² 4.7k; GND R³¹ 4.7k R³⁰ 4.7k GND; R²⁹ 4.7k GND; 1 STATUS1; 3 STATUS2; U9 VNLD5160TR-E GND GND; U11 VNLD5160TR-E GND; U10 VNLD5160TR-E OUT6; IN5 OUT4 OUT3 OUT5 OUT2 OUT1; GND R³⁰ 4.7k; R³¹ 4.7k GND R³² 4.7k GND GND R³⁴ 4.7k; GND R²⁹ 4.7k GND R³³ 4.7k

Hellen One : Power-Module interface

Reverse polarity and overvoltage protection
F410 V12_RAW


# 6 U751 GND

1u R761


Id: 1/1 Title: File: hellen1-vr-discrete.kicad_sch Sheet: /


File: hellen1-vr-max9924.kicad_sch Sheet: /
Id: 1/1 Title: VR MAX9924 module

33n R604

# 100n GND


1 PA4 10 PA5 11 PA6 12 PA7 13 PB0 14 PB1 15 VSS 16 VDDIO2 17 PA8 18 PA9 19 PF0 2 PA10 20 PA11 21 PA12 22 PA13 23 PA14 24 PA15 25 PB3 26 PB4 27 PB5 28 PB6 29 PF1 3 PB7 30 PB8 31 VSSA 32 NRST 4 VDDA

to ground to improve the routing

File: hellen1-wbo.kicad_sch Sheet: / rusefi.com

Vdd 4; Vss 6; MCP6004; GNDA; OUT1; OUT2; OUT3; OUT4

Vdd 4; Vss 6; MCP6004; GNDA; OUT1; OUT2; OUT3; OUT4

SPI_; VCC; 5 SPI_SCK; 7 SPI_O; lex MicroSD; _MIS


R143 populated: analog input O2S
R145 populated: WAKEUP by CAN

*VIGN input is unprotected!
*A21 is duplicated for ADC and EINT


See pullups replacement file for actual values


# See pullups replacement file for actual values


VRE; _CRA; _CLT; IAT; _IAT; VIG; nRes; VBAT; SWCL; SPI2; _MIS; SPI3; I2C_SCL; SPI1; PWR_; GRE; u mcu.Sch; _IGN; 8.Sch; _can can.Sch; d.Sch; nRS; USB_; P USB_; USBI; A I2C_SCL UART8_RX UART8_TX UART2_RX UART2_TX; N VBAT; VCC; ACC_SC; ACC_; ACC_MIS; ACC_MO; BARO; sen; ors.Sc; LVC1; VBU; wer.Sch; USBID (PA; USBM (PA; USBP (PA; 8 SWDIO (PA13); N5 SWCLK (PA14); N6 nReset; _SCK (PC1; _MISO (PC1; _MOSI (PC1; I2C_SCL (PB1; 3 I2C_SDA (PB11); E4 UART2_TX (PD5); _SCK; _MISO (PB1; _MOSI (PB1; _PWM2 (PC6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

USBM USBP USBID VBUS
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

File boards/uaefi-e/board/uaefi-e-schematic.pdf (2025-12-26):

3V3 | DC Driver 1 OUT5
IGN1_(PC13) W10 | CANH | W11 CANL | W12 V33_REF W13 | V5A_SWITCHABLE W14 V5A_SWITCHABLE | W2


Injection General purpose bus

Analog inputs (sensors) LS & HS outputs Discrete inputs A
8 +12V_RAW

Analog/digital Heater negative Power GND

3V3 12 GND 13 EN 15 ALED 16 STAT 17 RXD 2

enable the CAN WAKEUP

analog signal VR-DISCRETE

https://rusefi.com/s/uaefi
Id: 1/9 Title: UAEFI File: uaefi.kicad_sch Sheet: / rusEFI.com


D Date: 2025-04-30 KiCad; E.D.A. 8.0.9 Size: A4; Rev:; GND GND; GND R¹² 4.7k R¹¹ 4.7k GND GND; R¹³ 4.7k; 1 STATUS1; 3 STATUS2; U7 VNLD5160TR-E; U8 VNLD5160TR-E; R¹⁰ 4.7k GND; IN2 OUT1; IN4 OUT3 OUT2 OUT4; R¹⁰ 4.7k GND GND R¹³ 4.7k GND R¹¹ 4.7k; R¹² 4.7k GND

Id: 3/9 Title: UAEFI File: LS4.kicad_sch Sheet: /LS/ rusEFI.com

D Date: 2025-04-30 KiCad; E.D.A. 8.0.9 Size: A4; Rev:; Id: 6/9 Title: UAEFI File: LS_HOT.kicad_sch Sheet: /LS; HOT/ rusEFI.com; GND R¹⁶ 4.7k GND; R¹⁵ 4.7k; 1 STATUS1; 3 STATUS2; U6 VNLD5160TR-E GND; IN2 OUT1 OUT2; R¹⁵ 4.7k GND R¹⁶ 4.7k; GND

D Date: 2025-04-30 KiCad; E.D.A. 8.0.9 Size: A4; Rev:; VOUT; 1 GND; 2 VCC; 6 U3 MPX4/MPXH6400_MAP; GND GND; OUT U3 MPX4/MPXH6400_MAP

Id: 8/9 Title: UAEFI File: MAP.kicad_sch Sheet: /MAP/ rusEFI.com


Id: 9/9 Title: UAEFI File: IGN6.kicad_sch Sheet: /Ignition/ rusEFI.com


Id: 9/9 Title: UAEFI File: egt.kicad_sch Sheet: /EGT/ rusEFI.com GND

6 ABCD; ABCD Date: 2025-04-30 KiCad; E.D.A. 8.0.9 Size: A4; Rev:; Id: 10/9 Title: UAEFI File: INJ6.kicad_sch Sheet: /Injector/ rusEFI.comR³³ 4.7k GND R³⁴ 4.7k GND GND R³² 4.7k; GND R³¹ 4.7k R³⁰ 4.7k GND; R²⁹ 4.7k GND; 1 STATUS1; 3 STATUS2; U9 VNLD5160TR-E GND GND; U11 VNLD5160TR-E GND; U10 VNLD5160TR-E OUT6; IN5 OUT4 OUT3 OUT5 OUT2 OUT1; GND R³⁰ 4.7k; R³¹ 4.7k GND R³² 4.7k GND GND R³⁴ 4.7k; GND R²⁹ 4.7k GND R³³ 4.7k

Hellen One : Power-Module interface

Reverse polarity and overvoltage protection
F410 V12_RAW


# 6 U751 GND

1u R761


Id: 1/1 Title: File: hellen1-vr-discrete.kicad_sch Sheet: /


File: hellen1-vr-max9924.kicad_sch Sheet: /
Id: 1/1 Title: VR MAX9924 module

+3.3V C616

27k +


100n GND GND R⁶⁰⁸ ⁴⁷

1 PA4 10 PA5 11 PA6 12 PA7 13 PB0 14 PB1 15 VSS 16 VDDIO2 17 PA8 18 PA9 19 PF0 2 PA10 20 PA11 21 PA12 22 PA13 23 PA14 24 PA15 25 PB3 26 PB4 27 PB5 28 PB6 29 PF1 3 PB7 30 PB8 31 VSSA 32 NRST 4 VDDA

1u GND GND GND
+3.3V R⁶¹¹ ²⁰k R⁶¹⁰ ²⁰k GND

to ground to improve the routing
(floating pins by the software).

Heater negative Power GND

VDDA GND
Nernst Sense Voltage Buffer Nernst Internal Resistance Measurement

+3.3V C606 DNP GND
File: hellen1-wbo.kicad_sch Sheet: / rusefi.com V⁻ 11 V⁺

Vdd 4; Vss 6; MCP6004; GNDA; OUT1; OUT2; OUT3; OUT4

Vdd 4; Vss 6; MCP6004; GNDA; OUT1; OUT2; OUT3; OUT4

SPI_; VCC; 5 SPI_SCK; 7 SPI_O; lex MicroSD; _MIS


R143 populated: analog input O2S
R145 populated: WAKEUP by CAN

*VIGN input is unprotected!
*A21 is duplicated for ADC and EINT


See pullups replacement file for actual values


# See pullups replacement file for actual values


VRE; _CRA; _CLT; IAT; _IAT; VIG; nRes; VBAT; SWCL; SPI2; _MIS; SPI3; I2C_SCL; SPI1; PWR_; GRE; u mcu.Sch; _IGN; 8.Sch; _can can.Sch; d.Sch; nRS; USB_; P USB_; USBI; A I2C_SCL UART8_RX UART8_TX UART2_RX UART2_TX; N VBAT; VCC; ACC_SC; ACC_; ACC_MIS; ACC_MO; BARO; sen; ors.Sc; LVC1; VBU; wer.Sch; USBID (PA; USBM (PA; USBP (PA; 8 SWDIO (PA13); N5 SWCLK (PA14); N6 nReset; _SCK (PC1; _MISO (PC1; _MOSI (PC1; I2C_SCL (PB1; 3 I2C_SDA (PB11); E4 UART2_TX (PD5); _SCK; _MISO (PB1; _MOSI (PB1; _PWM2 (PC6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

USBM USBP USBID VBUS
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

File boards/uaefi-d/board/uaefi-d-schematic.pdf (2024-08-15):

IN3 Ignition OUT+ OUT- PWR | PWM
IGN1_(PC13) W10 | CANH | W11 CANL | W12 V33_REF W13 | V5A_SWITCHABLE W14 V5A_SWITCHABLE | W2


LS & HS outputs Discrete inputs

Analog/digital Heater negative Power GND

3V3 12 GND 13 EN 15 ALED 16 STAT 17 RXD 2

enable the CAN WAKEUP

analog signal VR-DISCRETE
instead of the knock signal

https://rusefi.com/s/uaefi
Id: 1/9 Title: UAEFI File: uaefi.kicad_sch Sheet: / rusEFI.com


D Date: 2024-08-15 KiCad; E.D.A. 8.0.4 Size: A4; Rev:; GND; +12V_RAW; GND GND; GND R¹² 4.7k; R¹¹ 4.7k +12V_RAW; R¹³ 4.7k GND; 1 STATUS1; 3 STATUS2; U8 VNLD5160TR-E; U7 VNLD5160TR-E; R¹⁰ 4.7k; OUT1 OUT4 OUT3; IN1 OUT2; R¹⁰ 4.7k GND GND R¹³ 4.7k GND R¹¹ 4.7k; R¹² 4.7k GND

Id: 3/9 Title: UAEFI File: LS4.kicad_sch Sheet: /LS/ rusEFI.com

D Date: 2024-08-15 KiCad; E.D.A. 8.0.4 Size: A4; Rev:; Id: 6/9 Title: UAEFI File: LS_HOT.kicad_sch Sheet: /LS; HOT/ rusEFI.com; GND R¹⁶ 4.7k GND; R¹⁵ 4.7k; 1 STATUS1; 3 STATUS2; U6 VNLD5160TR-E GND; IN2 OUT1 OUT2; R¹⁵ 4.7k GND R¹⁶ 4.7k; GND

D Date: 2024-08-15 KiCad; E.D.A. 8.0.4 Size: A4; Rev:; VOUT; 1 GND; 2 VCC; 6 U3 MPX4/MPXH6400_MAP; GND GND; OUT U3 MPX4/MPXH6400_MAP

Id: 8/9 Title: UAEFI File: MAP.kicad_sch Sheet: /MAP/ rusEFI.com


Id: 9/9 Title: UAEFI File: IGN6.kicad_sch Sheet: /Ignition/ rusEFI.com


Id: 9/9 Title: UAEFI File: egt.kicad_sch Sheet: /EGT/ rusEFI.com GND

6 ABCD; ABCD Date: 2024-08-15 KiCad; E.D.A. 8.0.4 Size: A4; Rev:; Id: 10/9 Title: UAEFI File: INJ6.kicad_sch Sheet: /Injector/ rusEFI.comR³³ 4.7k GND R³⁴ 4.7k GND GND R³² 4.7k; GND R³¹ 4.7k R³⁰ 4.7k GND; R²⁹ 4.7k GND; 1 STATUS1; 3 STATUS2; U9 VNLD5160TR-E GND GND; U11 VNLD5160TR-E GND; U10 VNLD5160TR-E OUT6; IN5 OUT4 OUT3 OUT5 OUT2 OUT1; GND R³⁰ 4.7k; R³¹ 4.7k GND R³² 4.7k GND GND R³⁴ 4.7k; GND R²⁹ 4.7k GND R³³ 4.7k

Hellen One : Power-Module interface

Reverse polarity and overvoltage protection
F410 V12_RAW


# 6 U751 GND

1u R761


Id: 1/1 Title: File: hellen1-vr-discrete.kicad_sch Sheet: /


File: hellen1-vr-max9924.kicad_sch Sheet: /
Id: 1/1 Title: VR MAX9924 module

+3.3V C616

27k +


100n GND GND R⁶⁰⁸ ⁴⁷

1 PA4 10 PA5 11 PA6 12 PA7 13 PB0 14 PB1 15 VSS 16 VDDIO2 17 PA8 18 PA9 19 PF0 2 PA10 20 PA11 21 PA12 22 PA13 23 PA14 24 PA15 25 PB3 26 PB4 27 PB5 28 PB6 29 PF1 3 PB7 30 PB8 31 VSSA 32 NRST 4 VDDA

1u GND GND GND
+3.3V R⁶¹¹ ²⁰k R⁶¹⁰ ²⁰k GND

to ground to improve the routing
(floating pins by the software).

Heater negative Power GND

VDDA GND
Nernst Sense Voltage Buffer Nernst Internal Resistance Measurement

+3.3V C606 DNP GND
File: hellen1-wbo.kicad_sch Sheet: / rusefi.com V⁻ 11 V⁺

Vdd 4; Vss 6; MCP6004; GNDA; OUT1; OUT2; OUT3; OUT4; C180 PIC18001 100n; PIC18002 COC3; PIR18001; PIR18002; PIR18003; PIR18004; PIR18005; PIR18006; PIR18007; PIR18008; COR5; PIR18101; PIR18102; PIR18103; PIR18105; PIR18104; PIR18106; PIR18107; PIR18108; COR6; PIU18001; PIU18002; PIU18003; PIU18004; PIU18005; PIU18006; PIU18007; PIU18008; PIU18009; PIU180010; PIU180011; PIU180012; PIU180013; PIU180014; COU2; PIC18001; POOUT2; POOUT1; POOUT3; POOUT4; POIN1; POIN3 PIU18005; PIU180010 POIN4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

Vdd 4; Vss 6; MCP6004; GNDA; OUT1; OUT2; OUT3; OUT4; C185 PIC18501 100n; PIC18502 COC3; PIR18501; PIR18502; PIR18503; PIR18504; PIR18505; PIR18506; PIR18507; PIR18508; COR5; PIR18601; PIR18602; PIR18603; PIR18605; PIR18604; PIR18606; PIR18607; PIR18608; COR6; PIU18501; PIU18502; PIU18503; PIU18504; PIU18505; PIU18506; PIU18507; PIU18508; PIU18509; PIU185010; PIU185011; PIU185012; PIU185013; PIU185014; COU2; PIC18501; POOUT2; POOUT1; POOUT3; POOUT4; POIN1; POIN3 PIU18505; PIU185010 POIN4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

SPI_; VCC; 5 SPI_SCK; 7 SPI_O; lex MicroSD; _MIS


R143 populated: analog input O2S
R145 populated: WAKEUP by CAN

*VIGN input is unprotected!
*A21 is duplicated for ADC and EINT



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

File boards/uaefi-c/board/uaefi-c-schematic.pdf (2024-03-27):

IN2 OUT1 | IN1 OUT2 LS HOT OUT+ OUT- PWR | PWM

# IN3 LS OUT5


Analog/digital Heater negative Power GND

3V3 12 GND 13 EN 15 ALED 16 STAT 17 RXD 2

enable the CAN WAKEUP
input will be unavailable.

analog signal VR-DISCRETE
instead of the knock signal

Hellen-One-PCB-logo

https://rusefi.com/s/uaefi
Id: 1/9 Title: UAEFI File: uaefi.kicad_sch Sheet: / rusEFI.com


D Date: 2023-11-01 KiCad; kicad-cli; 7.0.11-7.0.11~ubuntu22.04.1 Size: A4; Rev:; GND; +12V_RAW; GND GND; GND R¹² 4.7k; R¹¹ 4.7k +12V_RAW; R¹³ 4.7k GND; 1 STATUS1; 3 STATUS2; U8 VNLD5160TR-E; U7 VNLD5160TR-E; R¹⁰ 4.7k; OUT1 OUT4 OUT3; IN1 OUT2; R¹⁰ 4.7k GND GND R¹³ 4.7k GND R¹¹ 4.7k; R¹² 4.7k GND

File: LS4.kicad_sch Sheet: /LS/ rusefi.com

Id: 3/9 Title: UAEFI Low Side

D Date: 2023-11-01 KiCad; kicad-cli; 7.0.11-7.0.11~ubuntu22.04.1 Size: A4; Rev:; Id: 6/9 Title: UAEF Low Side always hot File: LS_HOT.kicad_sch Sheet: /LS; HOT/ rusefi.com; GND R¹⁶ 4.7k GND; R¹⁵ 4.7k; 1 STATUS1; 3 STATUS2; U6 VNLD5160TR-E GND; IN2 OUT1 OUT2; R¹⁵ 4.7k GND R¹⁶ 4.7k; GND

D Date: KiCad; kicad-cli; 7.0.11-7.0.11~ubuntu22.04.1 Size: A4; Rev:; VOUT; 1 GND; 2 VCC; 6 U3 MPX4/MPXH6400_MAP; GND GND; OUT U3 MPX4/MPXH6400_MAP

Id: 8/9 Title: File: MAP.kicad_sch Sheet: /MAP/


File: IGN6.kicad_sch Sheet: /Ignition/ rusefi.com

Id: 9/9 Title: UAEFI Ignition


Id: 9/9 Title: File: egt.kicad_sch Sheet: /EGT/

6 ABCD; ABCD Date: 2023-11-01 KiCad; kicad-cli; 7.0.11-7.0.11~ubuntu22.04.1 Size: A4; Rev:; Id: 10/9 Title: UAEFI Injector File: INJ6.kicad_sch Sheet: /Injector/ rusefi.comR³³ 4.7k GND R³⁴ 4.7k GND GND R³² 4.7k; GND R³¹ 4.7k R³⁰ 4.7k GND; R²⁹ 4.7k GND; 1 STATUS1; 3 STATUS2; U9 VNLD5160TR-E GND GND; U11 VNLD5160TR-E GND; U10 VNLD5160TR-E OUT6; IN5 OUT4 OUT3 OUT5 OUT2 OUT1; GND R³⁰ 4.7k; R³¹ 4.7k GND R³² 4.7k GND GND R³⁴ 4.7k; GND R²⁹ 4.7k GND R³³ 4.7k

Hellen One : Power-Module interface

Reverse polarity and overvoltage protection
F410 V12_RAW

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

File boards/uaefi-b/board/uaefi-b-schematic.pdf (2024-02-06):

# 3V3 DC Driver 2 OUT5

# IN3 Ignition OUT+ OUT- PWR PWM


Bus types General purpose bus

Injection Discrete inputs LS & HS outputs Analog inputs (sensors) DC Motor

Analog/digital Heater negative Power GND

3V3 12 GND 13 EN 15 ALED 16 STAT 17 RXD 2

enable the CAN WAKEUP
input will be unavailable.

use ADC3 for receiving
the analog signal VR1
instead of the knock

Hellen-One-PCB-logo

https://rusefi.com/s/uaefi
Id: 1/9 Title: UAEFI File: uaefi.kicad_sch Sheet: / rusEFI.com


D Date: 2023-11-01 KiCad; kicad-cli; 7.0.10-7.0.10~ubuntu22.04.1 Size: A4; Rev:; GND; +12V_RAW; GND GND; GND R¹² 4.7k; R¹¹ 4.7k +12V_RAW; R¹³ 4.7k GND; 1 STATUS1; 3 STATUS2; U8 VNLD5160TR-E; U7 VNLD5160TR-E; R¹⁰ 4.7k; OUT1 OUT4 OUT3; IN1 OUT2; R¹⁰ 4.7k GND GND R¹³ 4.7k GND R¹¹ 4.7k; R¹² 4.7k GND

File: LS4.kicad_sch Sheet: /LS/ rusefi.com
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

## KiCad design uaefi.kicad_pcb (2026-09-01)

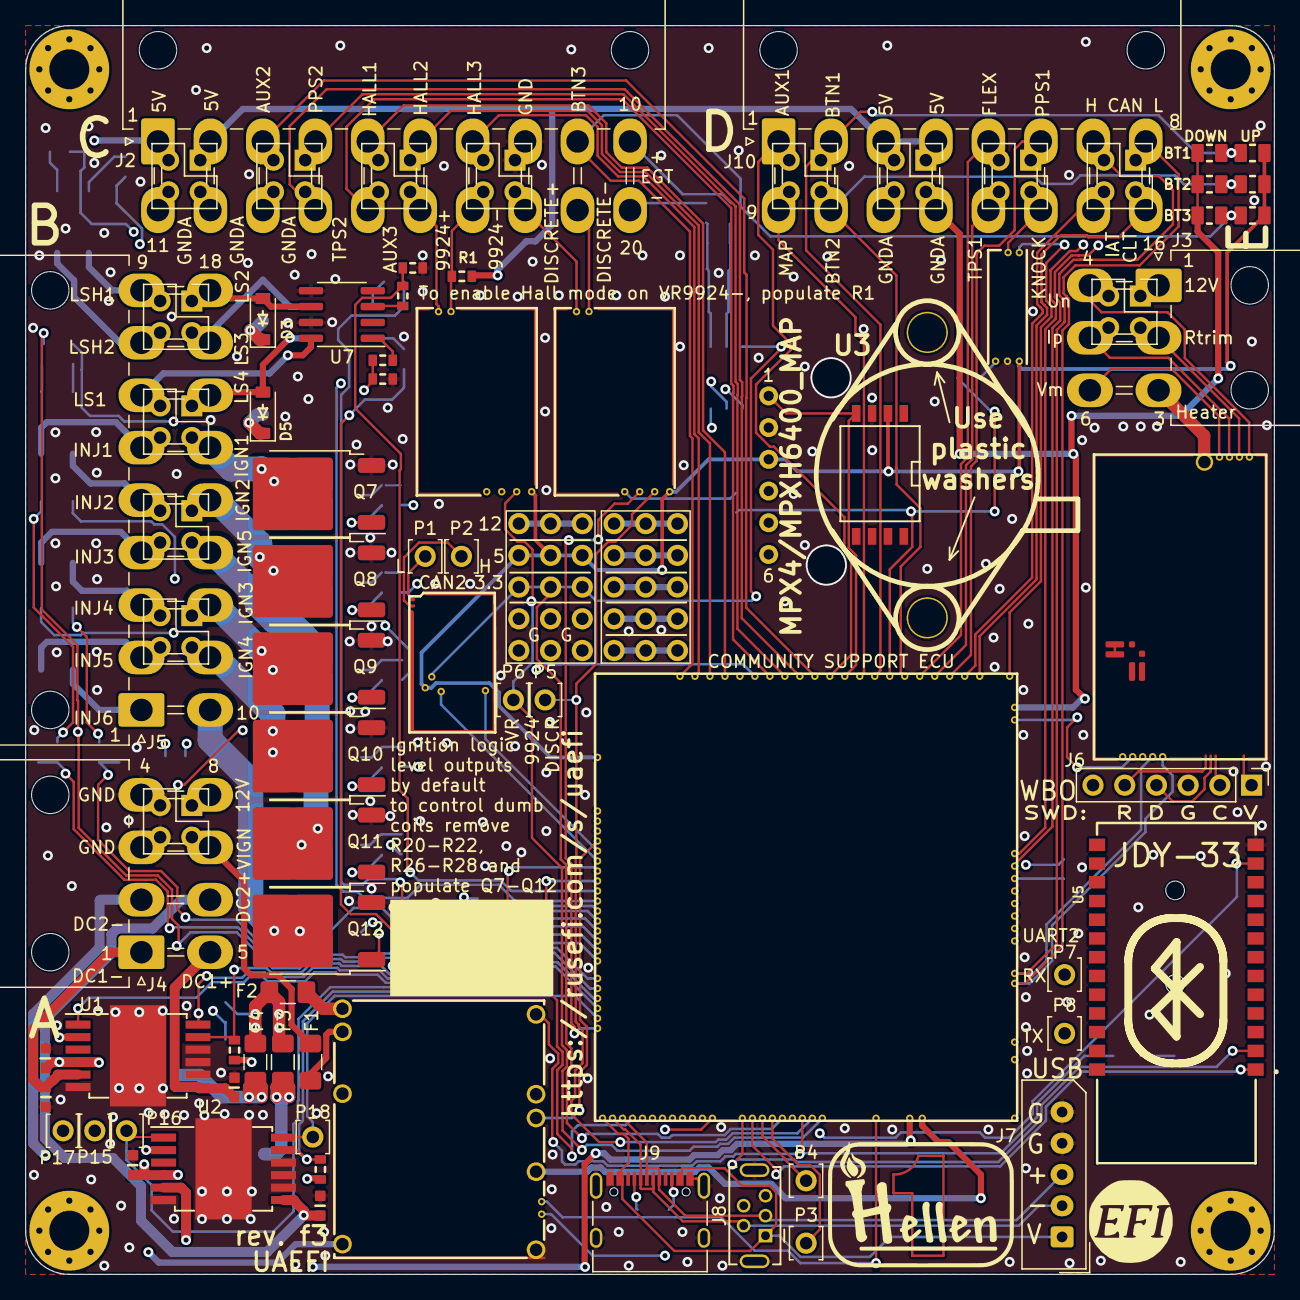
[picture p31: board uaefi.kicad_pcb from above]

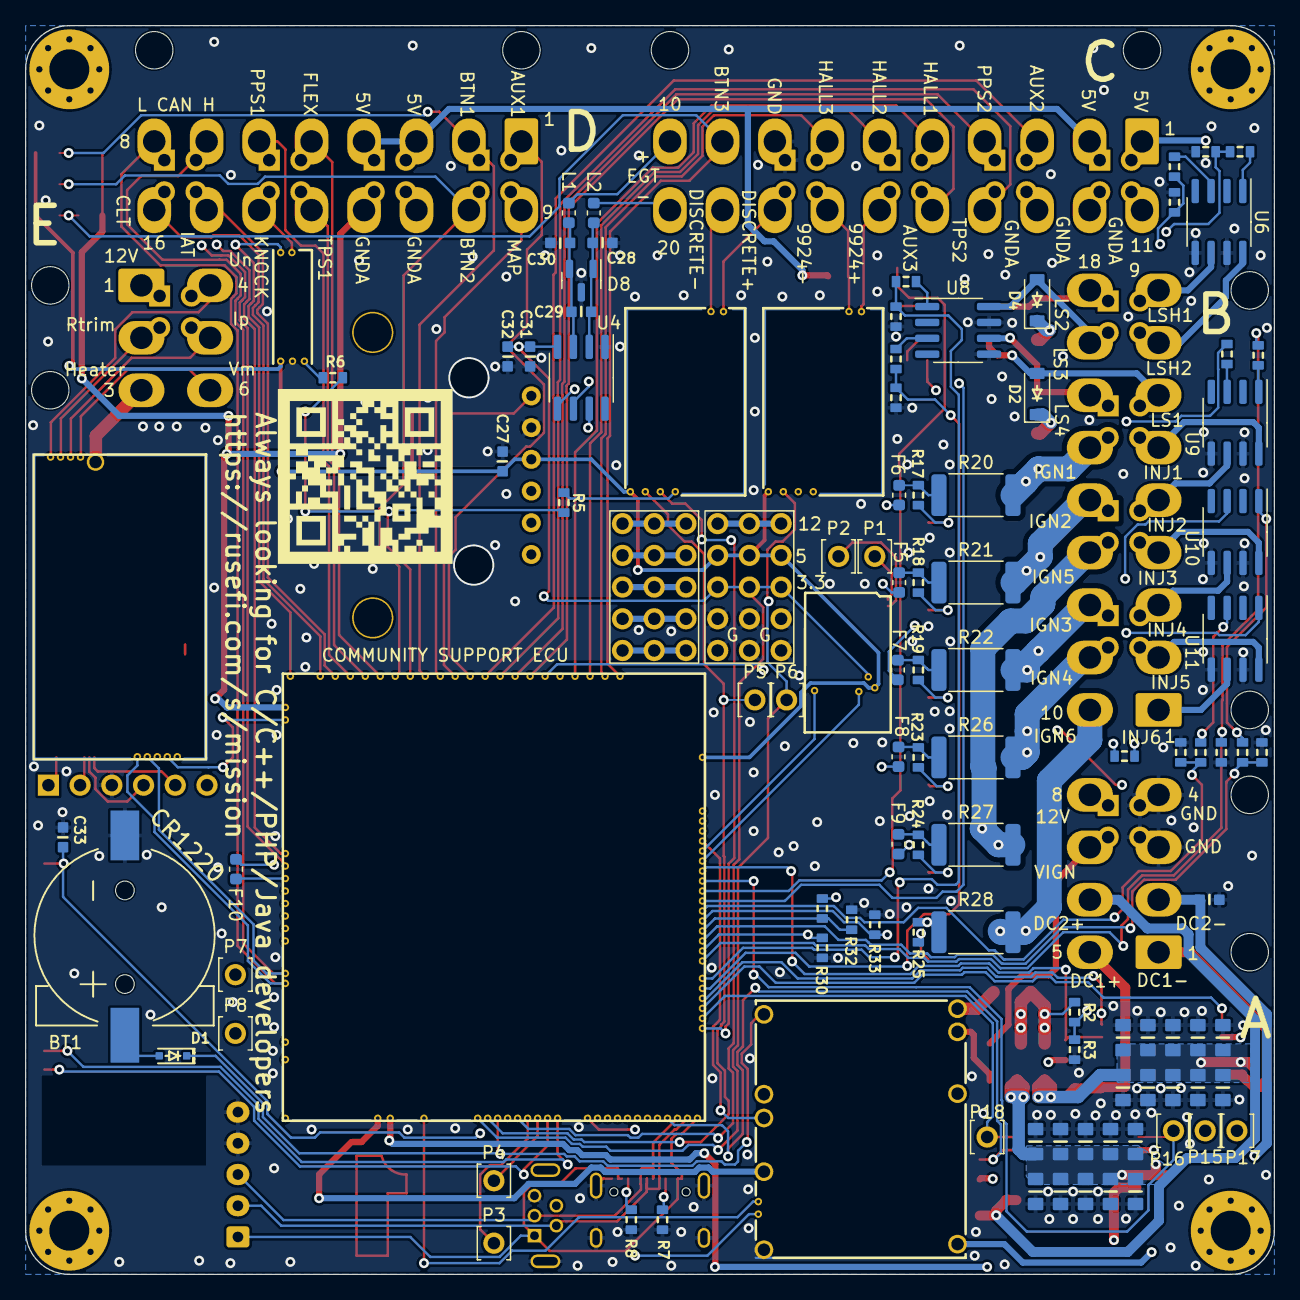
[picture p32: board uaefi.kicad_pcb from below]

Board: 4 copper layers, 100.0 x 100.0 mm, 170 parts (85 on the bottom side), 156 nets.

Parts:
BT1: CR1220; CR1220-2
C1, C2, C3, C4, C5, C6, C7, C8, C9, C10, C14, C15, C16, C17, C18, C19, C20, C21, C22, C23: 10u; C0805
C11, C24, C27, C29, C31, C33: 100n; C0603
C12, C13, C25, C26, C28, C30: 10n; C0603
C32: 1u; C0603
D1: 1N4148WS; SOD-323
D2, D3, D4, D5: B5819W; SOD-123
D8: NUP2105L; SOT-23
F1, F2, F3, F4: Fuse; Fuse_1206_3216Metric_Pad1.42x1.75mm_HandSolder
F5, F6, F7, F8, F9, F10: 50mA; Fuse_0603_1608Metric
G1: RUSEFI_LOGO; rusefi_logo
G2: LOGO
G3, G4: PROTO_AREA
H1, H2, H3, H4: M3; MountingHole_3.2mm_M3_Pad_Via
J1, J11, J12, J13, J14, J15, J16, J17, J18, J19, J20, J21, J22, J24: Conn_02x02_Odd_Even; PinSocket_2x02_P2.54mm_Vertical
J2: 5569-20A2; Molex_Mini-Fit_Jr_5569-20A2_2x10_P4.20mm_Horizontal
J3: 5569-06A2; Molex_Mini-Fit_Jr_5569-06A2_2x03_P4.20mm_Horizontal
J4: 5569-08A2; Molex_Mini-Fit_Jr_5569-08A2_2x04_P4.20mm_Horizontal
J5: 5569-18A2; Molex_Mini-Fit_Jr_5569-18A2_2x09_P4.20mm_Horizontal
J6: Conn_01x06; PinHeader_1x06_P2.54mm_Vertical
J7: Conn_01x05_Male; Molex_SPOX_5267-05A_1x05_P2.50mm_Vertical
J8: USB_B_Mini; USB-MINI-B-VERTICAL
J9: USB_C
J10: 5569-16A2; Molex_Mini-Fit_Jr_5569-16A2_2x08_P4.20mm_Horizontal
L1, L2: 470R@100MHz; L_0603_1608Metric
M1: Module-power_12and5V-0.3; power_12and5V
M2: Module-knock-0.2; knock
M3: Module-vr-discrete-0.5; vr-discrete
M4: Module-vr-max9924-0.1; vr-max9924
M5: Module-wbo-0.6; wbo
M6: Module:mega-mcu100/0.3; mega-mcu100
M7: Module-can-0.1; can
P1, P2, P3, P4, P5, P6, P7, P8, P15, P16, P17, P18: Pad; PAD-TH
Q7, Q8, Q9, Q10, Q11, Q12: ISL9V3040D3ST; TO-252-2
R1, R4, R9, R10, R11, R12, R13, R14, R15, R16, R29, R30, R31, R32, R33, R34, R41, R42, R43, R44, R45, R46, R47, R48, R49, R50, R51: 4.7k; R0603
R2: 33k; R0603
R3: 6.8k; R0603
R5, R6: 0; R0603
R7, R8: 5.6k; R0603
R17, R18, R19, R23, R24, R25: 22; R0603
R20, R21, R22, R26, R27, R28: 0; R_2512_6332Metric
R35, R36, R37: 10k; R0805
R38, R39, R40: DNP; R0805
U1, U2: TLE9201SG; Infineon_PG-DSO-12-11
U3: MPX4/MPXH6400_MAP; MPX-4_MAP
U4: MAX31855KASA; SOIC-8_3.9x4.9mm_P1.27mm
U5: JDY-33
U6, U7, U8, U9, U10, U11: VNLD5160TR-E; SOIC-8_3.9x4.9mm_P1.27mm

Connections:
+3.3V: M6.N21 (V33), R9.2, R14.2, U1.2 (VSO), U2.2 (VSO)
+3.3VA: C31.2, C32.2, C33.2, G3.3, G3.8, G3.13, M6.N15 (V33_SWITCHABLE), M7.V2 (CAN_VIO), U4.4 (V_{CC}), U5.12 (3V3)
+5V: M1.E4 (V5), M6.N22 (VCC)
+5VA: C27.2, G3.4, G3.9, G3.14, M2.E1 (V5A), M3.E4 (V5_IN), M4.E4 (V5_IN), M5.W1 (V5_IN), M6.E1 (V5A_SWITCHABLE), M6.W2 (V5A_SWITCHABLE), M7.V1 (V5), R38.2, R39.2, R40.2, U3.3 (VCC)
+5VP: J2.1, J2.2, J10.3, J10.4, J12.1, J12.2, J14.1, J14.2, M1.V4 (5VP), R1.1
+12V: F2.1, F3.1, F4.1, J4.8, J22.1, R2.2
+12V_RAW: D2.1 (K), D3.1 (K), D4.1 (K), D5.1 (K), F2.2, G3.5, G3.10, G3.15, J3.1, J24.1, M1.V1 (V12_PERM), M1.V3 (V12_RAW)
/1_WBO_Ip: J3.5, J24.4, M5.E3 (LSU_Ip)
/2_WBO_Vm: J3.6, M5.E2 (LSU_Vm)
/3_WBO_Heater: J3.3, M5.E5 (LSU_Htr)
/5_WBO_Rtrim: J3.2, J24.3, M5.E4 (LSU_Rtrim)
/6_WBO_Un: J3.4, J24.2, M5.E1 (LSU_Un)
/12V_KEY: F1.1, J4.7, J22.3
/ADC3: M6.S15 (IN_KNOCK_(PA2)), R5.2, R6.2
/CAN+: J1.2, J10.7, M5.W4 (CANH), M6.W11 (CANH)
/CAN-: J1.1, J10.8, M5.W3 (CANL), M6.W12 (CANL)
/DC1_DIR: M6.E21 (OUT_PWM4_(PC8)), P15.1, U1.1 (DIR)
/DC1_DIS: M6.E8 (SPI2_MISO_(PB14)), R9.1, U1.11 (DIS)
/DC1_PWM: M6.E20 (OUT_PWM3_(PC7)), P17.1, U1.12 (PWM)
/DC2_DIR: M6.E9 (SPI2_MOSI_(PB15)), P16.1, U2.1 (DIR)
/DC2_DIS: M6.N4 (USBID_(PA10)), R14.1, U2.11 (DIS)
/DC2_PWM: M6.E22 (OUT_PWM5_(PC9)), P18.1, U2.12 (PWM)
/DC Driver 1/PWR: C1.2, C2.2, C3.2, C4.2, C5.2, C6.2, C7.2, C8.2, C9.2, C10.2, C11.2, F4.2, U1.4 (VS)
/DC Driver 2/PWR: C14.2, C15.2, C16.2, C17.2, C18.2, C19.2, C20.2, C21.2, C22.2, C23.2, C24.2, F3.2, U2.4 (VS)
/EGT+: J2.10, L1.1
/EGT-: J2.20, L2.1
/EGT/SPI_CS: M6.N9 (SPI3_CS_(PA15)), U4.6 (~CS)
/IGN1: F6.2, M6.W10 (IGN1_(PC13))
/IGN2: F5.2, M6.W9 (IGN2_(PE5))
/IGN3: F7.2, M6.W8 (IGN3_(PE4))
/IGN4: F8.2, M6.W7 (IGN4_(PE3))
/IGN5: F9.2, M6.W6 (IGN5_(PE2))
/IGN6: F10.2, M6.W5 (IGN6_(PB8))
/INJ1: M6.E17 (OUT_INJ1_(PD3)), R29.2, R42.1
/INJ2: M6.E16 (OUT_INJ2_(PA9)), R30.2, R43.1
/INJ3: M6.E15 (OUT_INJ3_(PD11)), R31.2, R44.1
/INJ4: M6.E14 (OUT_INJ4_(PD10)), R32.2, R45.1
/INJ5: M6.E13 (OUT_INJ5_(PD2)), R33.2, R46.1
/INJ6: M6.E12 (OUT_INJ6_(PA8)), R34.2, R47.1
/INTERNAL_MAP: M6.S12 (IN_MAP2_(PC1)), U3.1 (VOUT)
/IN_AUX1: J10.1, J13.2, M6.S11 (IN_O2S_/_CAN_WAKEUP_(PA0))
/IN_AUX2: J2.3, J15.2, M6.S10 (IN_O2S2_(PA1))
/IN_AUX3: J2.15, J16.4, M6.S7 (IN_AUX3_(PA7))
/IN_BUTTON1: J10.2, J13.1, M6.S14 (IN_CRANK_(PB1)), R35.2, R38.1
/IN_BUTTON2: J10.10, J13.3, M6.S16 (IN_CAM_(PA6)), R36.2, R39.1
/IN_BUTTON3: J2.9, M6.S1 (IN_D4_(PE15)), R37.2, R40.1
/IN_CLT: J1.3, J10.16, M6.S21 (IN_CLT_(PC2))
/IN_FLEX: J10.5, J11.2, M6.S17 (IN_VSS_(PE11))
/IN_HALL1: J2.5, J16.2, M6.S4 (IN_D1_(PE12))
/IN_HALL2: J2.6, J16.1, M6.S3 (IN_D2_(PE13))
/IN_HALL3: J2.7, J17.2, M6.S2 (IN_D3_(PE14))
/IN_IAT: J1.4, J10.15, M6.S20 (IN_IAT_(PC3))
/IN_KNOCK: M2.E3 (OUT_KNOCK), R6.1
/IN_KNOCK_RAW: J10.14, J11.3, M2.W1 (IN_KNOCK)
/IN_MAP: J10.9, J13.4, M6.S13 (IN_MAP1_(PC0))
/IN_PPS1: J10.6, J11.1, M6.S19 (IN_PPS_(PA3))
/IN_PPS2: J2.4, J15.1, M6.S8 (IN_AUX2_(PC4/PE9))
/IN_TPS1: J10.13, J11.4, M6.S18 (IN_TPS_(PA4))
/IN_TPS2: J2.14, J15.3, M6.S9 (IN_AUX1_(PB0))
/IN_VIGN: F1.2, M1.V2 (IN_VIGN)
/IN_VMAIN: M6.S6 (IN_AUX4_(PC5)), R2.1, R3.2
/LS1: M6.E11 (OUT_INJ7_(PD15)), R10.2, R48.1
/LS2: M6.E10 (OUT_INJ8_(PD12)), R11.2, R49.1
/LS3: M6.E18 (OUT_PWM1_(PD13)), R12.2, R50.1
/LS4: M6.E19 (OUT_PWM2_(PC6)), R13.2, R51.1
/LS_HOT1: M6.W4 (IGN7_(PB9)), R16.1, R41.1
/LS_HOT2: M6.W3 (IGN8_(PE6)), R4.1, R15.1
/MISO3: M6.N11 (SPI3_MISO_(PC11)), U4.7 (SO)
/OUT_DC1+: C13.2, J4.5, U1.7 (OUT2)
/OUT_DC1-: C12.2, J4.1, U1.5 (OUT1)
/OUT_DC2+: C26.2, J4.6, U2.7 (OUT2)
/OUT_DC2-: C25.2, J4.2, U2.5 (OUT1)
/OUT_IGN1: J5.15, J19.3, Q7.2 (C), R20.2
/OUT_IGN2: J5.14, J20.1, Q8.2 (C), R21.2
/OUT_IGN3: J5.12, J21.1, Q9.2 (C), R22.2
/OUT_IGN4: J5.11, J21.3, Q10.2 (C), R26.2
/OUT_IGN5: J5.13, J20.3, Q11.2 (C), R27.2
/OUT_IGN6: J5.10, Q12.2 (C), R28.2
/OUT_INJ1: J5.6, J19.4, U9.8 (D1)
/OUT_INJ2: J5.5, J20.2, U9.6 (D2)
/OUT_INJ3: J5.4, J20.4, U10.8 (D1)
/OUT_INJ4: J5.3, J21.2, U10.6 (D2)
/OUT_INJ5: J5.2, J21.4, U11.8 (D1)
/OUT_INJ6: J5.1, U11.6 (D2)
/OUT_LS1: D2.2 (A), J5.7, J19.2, U7.8 (D1)
/OUT_LS2: D3.2 (A), J5.18, J18.1, U7.6 (D2)
/OUT_LS3: D4.2 (A), J5.17, J18.3, U8.8 (D1)
/OUT_LS4: D5.2 (A), J5.16, J19.1, U8.6 (D2)
/OUT_LS_HOT1: J5.9, J18.2, U6.6 (D2)
/OUT_LS_HOT2: J5.8, J18.4, U6.8 (D1)
/PG_5VP: M1.E6 (PG_5VP), M6.N12 (SPI3_MOSI_(PC12))
/PWR_EN: M1.E5 (EN_5VP), M6.N20 (OUT_PWR_EN_(PE10))
/SCK3: M6.N10 (SPI3_SCK_(PC10)), U4.5 (SCK)
/USB+: J7.3, J8.3 (D+), J9.A6 (D+), J9.B6 (D+), M6.N3 (USBP_(PA12))
/USB-: J7.2, J8.2 (D-), J9.A7 (D-), J9.B7 (D-), M6.N2 (USBM_(PA11))
/VBAT: D1.1 (K), M1.E1 (VBAT), M6.N17 (VBAT)
/VBUS: J7.1, J8.1 (VBUS), J9.A4 (VBUS), J9.A9 (VBUS), J9.B4 (VBUS), J9.B9 (VBUS), M6.N1 (VBUS)
/VIGN: M1.E3 (VIGN), M6.E5 (IN_VIGN_(PA5))
/VREF1: M2.W2 (VREF), M6.S22 (VREF1)
/VR_DISCRETE: M3.E3 (OUT), M6.N18 (UART8_RX_(PE0)), P5.1
/VR_DISCRETE+: J2.18, J17.3, M3.W2 (VR+)
/VR_DISCRETE-: J2.19, M3.W1 (VR-)
/VR_DISCRETE_A: M3.E2 (OUT_A), R5.1
/VR_DISCRETE_THR: M3.E1 (Thresh_IN), M6.E23 (OUT_PWM6_(PD14))
/VR_MAX9924: M4.E3 (OUT), M6.N19 (UART8_TX_(PE1)), P6.1
/VR_MAX9924+: J2.16, J16.3, M4.W2 (VR+)
/VR_MAX9924-: J2.17, J17.4, M4.W1 (VR-), R1.2
GND: BT1.2 (-), C1.1, C2.1, C3.1, C4.1, C5.1, C6.1, C7.1, C8.1, C9.1, C10.1, C11.1, C12.1, C13.1, C14.1, C15.1, C16.1, C17.1, C18.1, C19.1, C20.1, C21.1, C22.1, C23.1, C24.1, C25.1, C26.1, C27.1, C28.1, C30.1, C31.1, C32.1, C33.1, D8.3 (A), G3.1, G3.2, G3.6, G3.7, G3.11, G3.12, J2.8, J4.3, J4.4, J6.3, J7.4, J7.5, J8.5 (GND), J8.6 (Shield), J9.A1 (GND), J9.A12 (GND), J9.B1 (GND), J9.B12 (GND), J9.S1 (SHIELD), J17.1, J22.2, J22.4, M1.S1 (GND), M2.E2 (GND), M3.G (GND), M4.G (GND), M5.G (GND), M6.G (GND), M7.E1 (GND), Q7.3 (E), Q8.3 (E), Q9.3 (E), Q10.3 (E), Q11.3 (E), Q12.3 (E), R3.1, R7.1, R8.1, R10.1, R11.1, R12.1, R13.1, R15.2, R16.2, R29.1, R30.1, R31.1, R32.1, R33.1, R34.1, U1.6 (GND), U1.8 (SI), U1.9 (CSN), U1.10 (SCK), U1.13 (GND), U2.6 (GND), U2.8 (SI), U2.9 (CSN), U2.10 (SCK), U2.13 (GND), U3.2 (GND), U4.1 (GND), U5.13 (GND), U6.5 (S2), U6.7 (S1), U7.5 (S2), U7.7 (S1), U8.5 (S2), U8.7 (S1), U9.5 (S2), U9.7 (S1), U10.5 (S2), U10.7 (S1), U11.5 (S2), U11.7 (S1)
GNDA: J2.11, J2.12, J2.13, J10.11, J10.12, J12.3, J12.4, J14.3, J14.4, J15.4, M6.W1 (GNDA), R35.1, R36.1, R37.1
unnamed: BT1.1 (+), D1.2 (A)
unnamed: F5.1, R18.2, R21.1
unnamed: F6.1, R17.2, R20.1
unnamed: F7.1, R19.2, R22.1
unnamed: F8.1, R23.2, R26.1
unnamed: F9.1, R24.2, R27.1
unnamed: F10.1, R25.2, R28.1
unnamed: G4.1, G4.6, G4.11
unnamed: G4.5, G4.10, G4.15
unnamed: G4.2, G4.7, G4.12
unnamed: G4.3, G4.8, G4.13
unnamed: G4.4, G4.9, G4.14
unnamed: J6.1, M5.W8 (V33_OUT)
unnamed: J6.2, M5.W7 (SWCLK)
unnamed: J6.4, M5.W6 (SWDIO)
unnamed: J6.5, M5.W5 (nReset)
unnamed: J9.A5 (CC1), R7.2
unnamed: J9.B5 (CC2), R8.2
unnamed: M5.J1 (SEL1), M5.J_GND1 (PULL_DOWN1)
unnamed: M6.N14a (LED_GREEN), P4.1
unnamed: M6.N14b (LED_YELLOW), P3.1
unnamed: M6.E6 (SPI2_CS_/_CAN2_RX_(PB12)), M7.V6 (CAN_RX)
unnamed: M6.E7 (SPI2_SCK_/_CAN2_TX_(PB13)), M7.V5 (CAN_TX)
unnamed: M6.N14 (UART2_RX_(PD6)), P7.1, U5.1 (TXD)
unnamed: M6.N13 (UART2_TX_(PD5)), P8.1, U5.2 (RXD)
unnamed: M7.S2 (CANH), P2.1
unnamed: M7.S1 (CANL), P1.1
unnamed: Q7.1 (G), R17.1
unnamed: Q8.1 (G), R18.1
unnamed: Q9.1 (G), R19.1
unnamed: Q10.1 (G), R23.1
unnamed: Q11.1 (G), R24.1
unnamed: Q12.1 (G), R25.1
unnamed: C29.2, C30.2, D8.2 (K), L1.2, U4.3 (T+)
unnamed: C28.2, C29.1, D8.1 (K), L2.2, U4.2 (T-)
unnamed: R4.2, U6.1 (IN1)
unnamed: R41.2, U6.3 (IN2)
unnamed: R48.2, U7.1 (IN1)
unnamed: R49.2, U7.3 (IN2)
unnamed: R50.2, U8.1 (IN1)
unnamed: R51.2, U8.3 (IN2)
unnamed: R42.2, U9.1 (IN1)
unnamed: R43.2, U9.3 (IN2)
unnamed: R44.2, U10.1 (IN1)
unnamed: R45.2, U10.3 (IN2)
unnamed: R46.2, U11.1 (IN1)
unnamed: R47.2, U11.3 (IN2)

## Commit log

2023-11-13 Upd SCH
    [DC_MOTOR_0.1.kicad_sch, IGN6.kicad_sch, INJ6.kicad_sch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]
2023-11-29 [skip actions] Auto-generated board
    [uaefi-B_Cu.gbl, uaefi-B_Mask.gbs, uaefi-B_Paste.gbp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]
2023-11-30 #6, #7, #8, #9
    [uaefi.kicad_sch]
2023-12-02 Shortage fix
    [bom_replace_uaefi-a.csv]
2023-12-02 Upd PCB
    [bom_replace_uaefi-a.csv, egt.kicad_sch, uaefi.kicad_pcb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]
2023-12-03 #18 #19 #20
    [uaefi.kicad_pcb, uaefi.kicad_sch]
2023-12-04 BOM substitutions
    [bom_replace_uaefi-a.csv]
2023-12-22 same thing just without connectors
    [uaefi-a-BOM-JLC-no-molex.csv]
2023-12-22 updating LEDs
    [uaefi-a-BOM-JLC-no-molex.csv, uaefi-a-BOM-JLC.csv]
2024-01-12 as-is copy
    [bom_replace_uaefi-b.csv]
2024-01-12 in progress
    [DC_MOTOR_0.1.kicad_sch, IGN6.kicad_sch, INJ6.kicad_sch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]
2024-01-13 C117, C123 fix again #32
    [bom_replace_uaefi-b.csv, uaefi-a-BOM-JLC-no-molex.csv, uaefi-a-BOM-JLC.csv]
2024-01-13 cost reduction ideas #35
    [bom_replace_uaefi-b.csv]
2024-01-15 more current Q
    [uaefi-a-BOM-JLC-no-molex.csv, uaefi-a-BOM-JLC.csv]
2024-02-05 [skip actions] Auto-generated board v2.1
    [uaefi-B_Cu.gbl, uaefi-B_Mask.gbs, uaefi-B_Paste.gbp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]
2024-02-06 Upd SCH, PCB
    [INJ6.kicad_sch, LS4.kicad_sch, LS_HOT.kicad_sch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]
2024-02-06 L420 shortage
    [bom_replace_uaefi-b.csv]
2024-02-06 just a copy
    [uaefi-b-BOM-JLC-no-moles.csv]
2024-02-06 without molex
    [uaefi-b-BOM-JLC-no-moles.csv]
2024-02-06 Blue 0402 LEDs shortage
    [bom_replace_uaefi-b.csv]
2024-02-27 more of same
    [uaefi-b-BOM-JLC-no-moles.csv, uaefi-b-BOM-JLC.csv]
2024-03-27 Rev C
    [bom_pullups_uaefi-c.csv, bom_replace_uaefi-c.csv, egt.kicad_sch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]
2024-04-05 rev C no molex BOM
    [uaefi-c-BOM-JLC-no-molex.csv]
2024-04-05 DNP BLUETOOTH JDY
    [bom_replace_uaefi-c.csv, uaefi-c-BOM-JLC-no-molex.csv, uaefi-c-BOM-JLC.csv]
2024-06-20 BOM update
    [uaefi-c-BOM-JLC.csv]
2024-08-15 #62 #65 #66 #67 #53
    [DC_MOTOR_0.1.kicad_sch, IGN6.kicad_sch, INJ6.kicad_sch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]
2024-12-16 rev D no molex
    [uaefi-d-BOM-JLC-no-molex.csv]
2025-04-30 Rev E
    [DC_MOTOR_0.1.kicad_sch, IGN6.kicad_sch, INJ6.kicad_sch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]
2025-05-15 rev E BOM copy without molex
    [uaefi-e-BOM-JLC-n-moles.csv]
2025-09-08 #81 #82 #86 #87
    [DC_MOTOR_0.1.kicad_sch, IGN6.kicad_sch, INJ6.kicad_sch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]
2025-09-10 no molex
    [uaefi-e-BOM-JLC-no-molex.csv]
2025-10-12 HowTo switch MAX9924 to B mode
2025-10-21 Revise capacitor values and add product links
    Updated capacitor recommendations for power rails with links.
2025-12-26 rebuild BOM
2025-12-26 restoring no-molex
    [uaefi-e-BOM-JLC-no-molex.csv]
2026-03-22 #106 #107 rev e2
    [bom_pullups_uaefi-e2.csv, bom_replace_uaefi-e2.csv, uaefi.kicad_pcb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]
2026-03-27 Update and rename enclosures.md to readme.md
2026-04-06 push poke
    [bom_replace_uaefi-e2.csv]
2026-07-05 Unification with UAEFI F7 #114 #110
    [DC_MOTOR_0.1.kicad_sch, IGN6.kicad_sch, INJ6.kicad_sch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]
2026-07-13 #118 #110 skip rev f
    [DC_MOTOR_0.1.kicad_sch, IGN6.kicad_sch, INJ6.kicad_sch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]
2026-07-13 Fix https://rusefi.com/s/uaefi main SCH link
    [uaefi.kicad_sch]
2026-09-01 #120 moved
    [uaefi.kicad_pcb]
2026-09-01 better clearance for metal enclosure
    [bom_pullups_uaefi-f3.csv, bom_replace_uaefi-f3.csv]
2026-09-01 rev.f3 #120
    [INJ6.kicad_sch, uaefi.kicad_pcb, uaefi.kicad_sch]
2026-09-01 Export F3
    [DC_MOTOR_0.1.kicad_sch, IGN6.kicad_sch, INJ6.kicad_sch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]
